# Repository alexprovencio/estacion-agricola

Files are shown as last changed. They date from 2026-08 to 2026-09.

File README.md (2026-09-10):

# Estación Agrícola Autónoma

Sistema de medición ambiental y del suelo para huertas al aire libre, construido como práctica final de **Sistemas Digitales para el Internet de las Cosas** y continuado en **Comunicaciones Inalámbricas y Protocolos para el Internet de las Cosas** (micromáster IoT, UNED, curso 2025/2026).

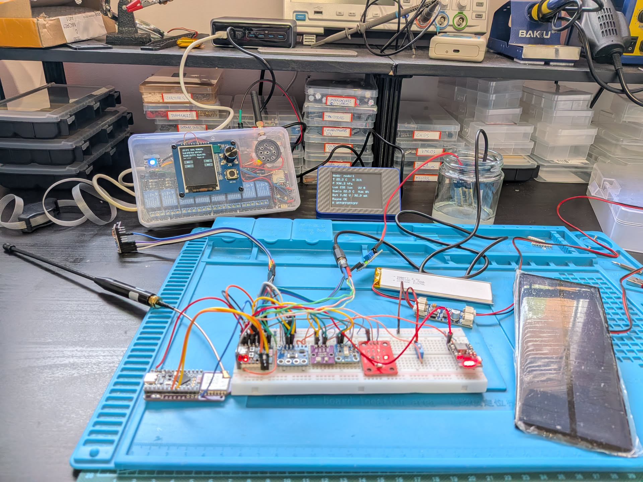
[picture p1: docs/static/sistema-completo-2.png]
Sistema completo


## Qué hace

Un **nodo autónomo** (ESP32-C3 SuperMini) mide *in situ* temperatura y humedad ambientales, presión atmosférica, iluminación, índice UV, humedad y temperatura del suelo y proximidad de tormentas. Envía sus lecturas en JSON cada 30 s a una **estación base** (Raspberry Pi 1 Model B) mediante LoRa con placas Faketec y firmware Meshtastic, aunque el enlace es intercambiable: WiFi con MQTT, ESP-NOW o USB directo. La estación base publica todo en un broker **Mosquitto** local, muestra los datos en pantalla, acciona relés, emite avisos de voz y los sube a la nube (Ubidots). Una **estación auxiliar** (Cheap Yellow Display o CYD) se conecta por WiFi al mismo broker para mostrar la telemetría y el estado de los relés en tiempo real.

## Estado del proyecto

- **Práctica Sistemas Digitales**: etiqueta [`sistemas-digitales-final`](https://github.com/alexprovencio/estacion-agricola/tree/sistemas-digitales-final).
- **Práctica Comunicaciones Inalámbricas**: rama `main`, memoria en [memoria-comunicaciones.md](docs/memoria-comunicaciones.md).

## Estructura del repositorio

```
├── nodo-autonomo/      Firmware del ESP32-C3 (pioarduino / Arduino), con varios targets de transporte
├── estacion-base/      Programa de la estación base (Python, paquete instalable) + broker Mosquitto
├── estacion-auxiliar/  Firmware del Cheap Yellow Display (ESP32 + TFT_eSPI)
├── puente-espnow/      Firmware del ESP32-C3 que hace de puente ESP-NOW
└── docs/               Memorias y material de referencia
```

## Documentación

Todo el detalle está en las memorias:

- [Memoria de Sistemas Digitales](docs/memoria-sistemas.md): arquitectura, sensores, conexiones, código, instalación y configuración del nodo y la estación base.
- [Memoria de Comunicaciones Inalámbricas](docs/memoria-comunicaciones.md): nodo solar, broker MQTT, enlaces WiFi/ESP-NOW/Meshtastic y comparación de prestaciones.
- [Diagrama de arquitectura](docs/arquitectura.mdd): flujo de datos entre nodo, gateway, broker, estación base y estación auxiliar.

## Nodo autónomo (firmware)

Proyecto [PlatformIO](https://platformio.org/) para el ESP32-C3 SuperMini con el framework Arduino y el fork `pioarduino` del core. Se compila y flashea con la extensión *pioarduino* de Visual Studio Code o desde terminal. El transporte se elige con el target de compilación:

```bash
cd nodo-autonomo
pio run -e esp32-c3-meshtastic --target upload   # LoRa/Meshtastic
pio run -e esp32-c3-wifi       --target upload   # WiFi + MQTT
pio run -e esp32-c3-espnow     --target upload   # ESP-NOW al puente
pio run -e esp32-c3-usb        --target upload   # USB-CDC directo a la base
```

El nodo se alimenta con panel solar y batería LiPo a través del cargador MPPT CN3791 y el convertidor MH-CD41, y mide su consumo con un INA226. Cada 30 s emite el payload JSON:

```json
{"nid":"nodo-1","seq":1,"t":31,"ta":25.9,"ha":30.1,"pa":935.1,"lx":771.8,"uv":23,"ts":24.1,"hs":2828,"vb":4,"ia":79.9,"pw":317.5,"re":"ok"}
```

La configuración (credenciales WiFi/MQTT, MAC del puente, canal ESP-NOW...) se copia de `include/secrets.h.example` a `include/secrets.h`. La lista de sensores, pines y librerías está en la [memoria](docs/memoria-comunicaciones.md#2-nodo-solar-autónomo).

## Estación base

Requisitos: Raspberry Pi con SPI y audio habilitados, las dependencias del sistema indicadas en la memoria, un broker **Mosquitto** local y Python 3.9 o superior.

```bash
cd estacion-base
python3 -m venv ~/venvs/estacion
source ~/venvs/estacion/bin/activate
pip install --upgrade pip
pip install -e .
cp .env.example .env          # tokens de Ubidots y credenciales del broker
sudo ~/venvs/estacion/bin/python -m estacion_base
```

Se ejecuta como `root` por el uso de DMA de la librería *neopixel* (ver memoria). El programa:

- Lee el nodo por el puerto serie (USB, puente ESP-NOW o Faketec Meshtastic) con el inyector `gateway_serial.py`, o directamente del broker si el nodo usa WiFi (`ENLACE_NODO=mqtt`), y publica en `esagrau/nodos/+/telemetria`.
- Se suscribe al broker local (TLS en el puerto `8883`) para procesar la telemetría y el estado de los relés.
- Dibuja en la pantalla, gestiona relés, encoder y avisos de voz, ejecuta automatismos locales y comunica con Ubidots cada 30 s.

## Estación auxiliar

Firmware para el Cheap Yellow Display (ESP32 con pantalla ILI9341 y TFT_eSPI). Se conecta por WiFi al broker de la estación base (puerto `1883`, sin TLS por limitaciones de la librería *AsyncMqttClient* en el ESP32) y se suscribe a `esagrau/nodos/+/telemetria` y `esagrau/base/estado` para mostrar las variables del nodo y el estado de los relés en tiempo real. Configuración en `include/secrets.h` (a partir de `secrets.h.example`).

```bash
cd estacion-auxiliar
pio run --target upload
```

## Puente ESP-NOW

Firmware para un segundo ESP32-C3 que recibe la telemetría del nodo por ESP-NOW y la reenvía por USB-CDC a la estación base, que la inyecta en el broker. Configuración en `include/secrets.h` (canal WiFi y MAC del nodo).

```bash
cd puente-espnow
pio run --target upload
```

## Broker MQTT

La estación base ejecuta un broker *Mosquitto* con un prefijo común `esagrau` (EStación AGRícola AUtónoma):

| Tema | Uso |
| :--- | :--- |
| `esagrau/nodos/{id}/telemetria` | Lecturas del nodo (QoS 1). |
| `esagrau/nodos/{id}/estado` | Presencia del nodo (retain, LWT en modo WiFi). |
| `esagrau/nodos/{id}/control` | Control puntual del nodo (uso futuro). |
| `esagrau/base/estado` | Estado de los relés de la estación base (retain). |
| `esagrau/base/control` | Petición de cambio de relés (base, auxiliar, Ubidots). |

La configuración del broker (`/etc/mosquitto/conf.d/local.conf`), los certificados y los usuarios se detallan en la [memoria](docs/memoria-comunicaciones.md#31-configuración-del-broker-mqtt).

## Conexiones

Los esquemas completos se generaron con Cirkit Designer y se citan en la [memoria de Sistemas Digitales](docs/memoria-sistemas.md), junto con la lista de pines del nodo (entradas analógicas, bus I2C, OneWire e interrupciones) y de la estación base (SPI para la pantalla, pines de relés, LED y botones). El nodo solar añade la etapa de alimentación (CN3791 + MH-CD41 + INA226) y las placas Faketec para LoRa.

## Configuración de Ubidots

La estación base publica en dos dispositivos separados: `nodo-1` con las lecturas de los sensores y `estacion-base` con el estado de los relés, que además pueden activarse a distancia desde el panel. Más detalle en la [memoria](docs/memoria-sistemas.md#4-plataforma-iot-en-la-nube-ubidots).

## Mejoras previstas

Las líneas de trabajo futuras están recogidas en las conclusiones de la [memoria de Comunicaciones Inalámbricas](docs/memoria-comunicaciones.md#6-conclusiones-y-mejoras-futuras) (pruebas en campo abierto, PCBs propios, carcasas 3D, escalabilidad a varios nodos, etc.) y de la [memoria de Sistemas Digitales](docs/memoria-sistemas.md#5-conclusiones-y-mejoras-futuras).

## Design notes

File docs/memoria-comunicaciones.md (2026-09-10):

# 1. Introducción

Esta práctica continúa la realizada en la asignatura de Sistemas Digitales para el Internet de las Cosas. Consiste en el desarrollo de un sistema completo de mediciones ambientales y del suelo para agricultura inteligente, para su uso en huertas, viveros, invernaderos o cultivos extensos, fundamentalmente de regadío.

El sistema realiza las siguientes mediciones mediante un nodo autónomo instalado *in situ*:

- Temperatura ambiente: para detectar estrés térmico por calor o frío excesivos y predecir heladas.
- Humedad relativa del aire: podemos anticipar la aparición de enfermedades debidas a la alta humedad y, combinado con la temperatura, calcular la transpiración de las plantas con el fin de dimensionar el riego.
- Presión atmosférica: ayuda a la previsión meteorológica local, por ejemplo, una rápida caída de la presión puede indicar lluvia, viento o una tormenta.
- Iluminación incluyendo IR: ayuda a detectar exceso o déficit de luz en las plantas, lo que puede alterar su crecimiento. En un invernadero o cultivo bajo cubierta serviría para ajustar la iluminación artificial.[^1]
- Índice UV: afecta a la calidad, sabor y conservación de los frutos, además, lo podemos usar para proteger a los operarios los días de mayor incidencia o regular el uso de lámparas UVA en cultivos de interior.[^2]
- Proximidad de tormentas: nos puede servir para recolectar los frutos antes de la llegada de la tormenta evitando su deterioro a causa del granizo o la lluvia excesiva, también a preparar nuestros cultivos ante la tormenta, y puede evitar gastos innecesarios derivados de la aplicación de fitosanitarios que se desperdiciarían si se aplican justo antes de la lluvia.
- Temperatura del suelo: nos ayuda a encontrar el momento óptimo para la siembra, puede servirnos para calcular la disponibilidad de nutrientes y detectar riesgos de heladas.[^3]
- Humedad del suelo: fundamentalmente nos indica cuando regar, evitando riego en exceso o defecto, ahorrando agua y detectando problemas de drenaje.

Todas estas mediciones las realiza un nodo autónomo (ESP32-C3 SuperMini), equipado con un panel solar y una batería de litio, que se instala en la zona a medir y cuyos datos se envían a una estación base (Raspberry Pi 1 Model B) para su procesamiento y envío a una plataforma IoT en la nube (*Ubidots*) para su análisis.

La estación base dispone a su vez de una pantalla para visualización de los datos y/o alertas del sistema, botones que controlan una serie de relés que podrían usarse para activar bombas de riego, luces... y un altavoz que emite alertas (por ejemplo ante la proximidad de una tormenta) y avisos.

También se ha creado una estación auxiliar que muestra los datos del nodo autónomo y el estado de los relés de la estación base en tiempo real.

Finalmente, la comunicación entre el nodo autónomo y la estación base se realiza mediante LoRa usando dispositivos auxiliares con *Meshtastic*[^4] conectados por UART. La estación base, que usa un broker MQTT local, está conectada por Ethernet a mi red local y la estación auxiliar se conecta por WiFi a este broker para obtener los datos del sistema y mostrarlos.

Foto del sistema completo con el nodo autónomo en primer plano y las estaciones base y auxiliar detrás. Se pueden ver las placas Faketec con Meshtastic del nodo y la estación.

# 2. Nodo solar autónomo

El nodo autónomo, gobernado por un ESP32-C3 Supermini de TENSTAR ROBOT[^5], cuenta con los siguientes sensores de ambiente/suelo:

- Sensor AHT20+BMP280: mide temperatura, humedad relativa y presión atmosférica ambientales. El módulo que tengo combina ambos sensores y funciona por I2C.
- Sensor VEML7700: mide la luz ambiental real de forma lineal y con alta precisión y funciona por I2C. Rango de medición de 0 a 120.000 lux, detecta luz visible e IR.
- Sensor GUVA-S12SD: calcula el índice UV para luces de longitudes de onda de 240 nm a 370 nm con salida analógica y salida entre 0 y 1 V.
- Sensor AS3935: usado para detectar rayos y estimar la distancia a la tormenta. Puede detectar rayos hasta a 40 km con una precisión de 1 km en 14 pasos. Tiene un pin de alerta que conecto al ESP32-C3 para avisar de descargas en tiempo real mediante el uso de una interrupción y la lectura de un registro. Se puede conectar usando SPI o I2C, lo conecto usando I2C.
- Higrómetro de suelo FC-28: mide la humedad de la tierra usando un sensor simple por variación de conductividad. Uso la salida analógica con el ADC de 12 bits del ESP32-C3 para obtener valores entre 0 y 4096.
- Sonda Sumergible DS18B20: mide la temperatura, la emplearemos enterrada en la tierra. Usa el protocolo *OneWire*.

Los siguientes componentes se encargan de la alimentación:

- Sensor INA226: mide voltaje y corriente de la batería de litio conectada al sistema para calcular su carga y lo que consumimos. Funciona mediante I2C. Al hacer pruebas vi que el INA226 no me devolvía datos de corriente porque no había inicializado bien la librería con el registro de calibración: el valor del *shunt*, que en mi módulo es 0,1 Ω, y la corriente máxima medible, que según he visto es de alrededor de 0,8 A.
- Convertidor/Cargador MH-CD41: este módulo permite cargar baterías y además integra un convertidor a 5V, botón de encendido/apagado e indicador de carga. No lo empleo para cargar la batería, de eso se encarga el siguiente módulo.
- Cargador solar MPPT CN3791: eficiente módulo controlador de punto de máxima potencia para cargar baterías LiPo 1S desde un panel solar.
- Batería: LiPo de 1 Ah a 3,7 V para las pruebas.
- Panel solar: 165x65 mm de tamaño a 6 V con una salida máxima de 250 mA (1,5 W) para las pruebas.

Y para las comunicaciones con la estación base:

- Faketec V4[^6]: PCB con una placa de desarrollo con un nRF52840[^7] y una radio HT-RA62[^8] LoRa y firmware *Meshtastic*. Conectada por UART y que hace de pasarela con otra placa idéntica conectada a la estación base.

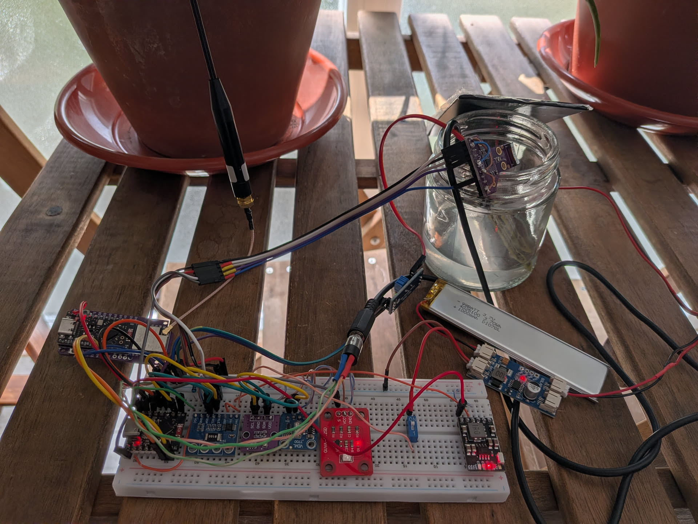
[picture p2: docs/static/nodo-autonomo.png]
Nodo autónomo en funcionamiento.


# 3. Estación base

La estación base, controlada por una Raspberry Pi 1 Model B, tiene los siguientes periféricos conectados mediante GPIO:

- Pantalla: la empleo para mostrar los datos recibidos del nodo, incluyendo alertas, y controlar los relés conectados a la estación base. Uso un módulo con una pantalla de 2 pulgadas con un codificador rotatorio y un botón extra integrados. Se conecta por SPI.
- LED de estado: empleado para indicar el estado del sistema. Uso un WS2812B conectado directamente.
- Amplificador y altavoz: usados para emitir alertas y avisos. Empleo un módulo con un PAM8302A, conectado al jack de 3,5 mm y a un pequeño altavoz de 8 Ω y 0,5 W.
- Relés: uso también un módulo con 8 relés para simular la apertura de válvulas de riego y la activación de otros sistemas. Solo conecto 4 de los relés, más que suficientes para realizar pruebas, y uso sus LEDs de estado para comprobar que funcionan correctamente.
- Faketec V4: idéntico al del nodo autónomo, conectado por UART usando los GPIO de la Raspberry Pi. Hay que activar el puerto y deshabilitar la consola en la configuración de *DietPi*.

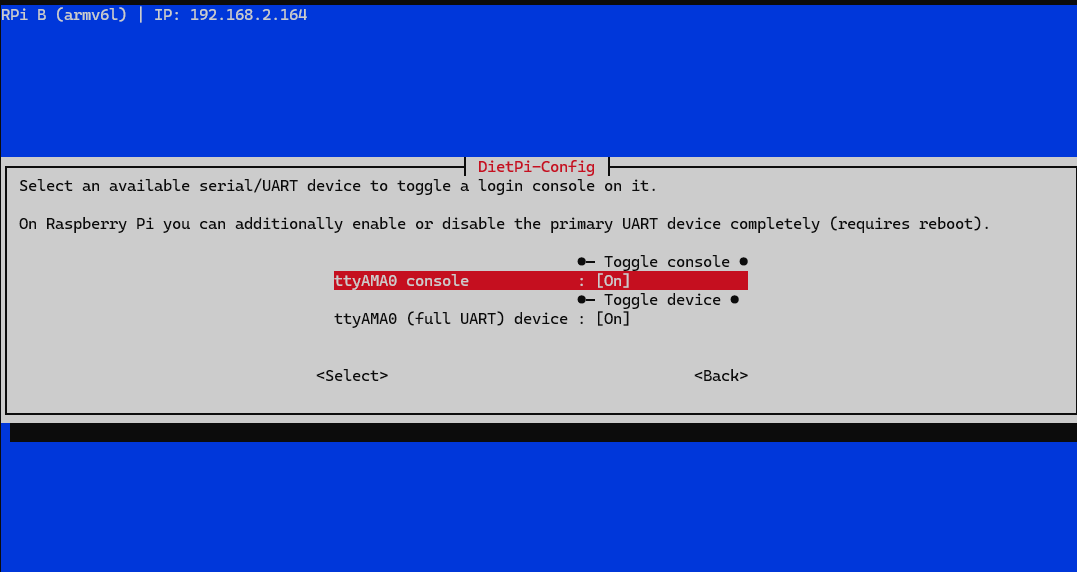
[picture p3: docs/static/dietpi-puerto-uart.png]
Configuración del puerto UART en DietPi


## 3.1. Configuración del broker MQTT

Instalo un broker *Mosquitto*[^9] en la Raspberry Pi. Lo hago usando el gestor de software de *DietPi*. El proceso de instalación se detalló en la Práctica 1 de la asignatura. Añado mi propia configuración en `/etc/mosquitto/conf.d/local.conf` para hacerlo más seguro, aunque como se ve he dejado la conexión insegura usando el puerto `1883` por simplicidad, lo ideal sería eliminarla y que todos los clientes se conectaran usando el puerto `8883`.

```bash
listener 1883 0.0.0.0
allow_anonymous false
password_file /etc/mosquitto/passwd

listener 8883 0.0.0.0
allow_anonymous false
cafile /etc/mosquitto/certs/ca.crt
certfile /etc/mosquitto/certs/server.crt
keyfile /etc/mosquitto/certs/server.key
require_certificate false
tls_version tlsv1.2
```

Creo usuarios y contraseñas para `nodo-1`, `estacion-base` y `estacion-aux` usando `mosquitto_passwd`. Genero los certificados autofirmados pertinentes para la conexión segura y finalmente reinicio el broker usando `sudo dietpi-services restart mosquitto`. El único cliente que usa la conexión segura con el broker MQTT es la propia estación base en local, debido a las limitaciones de tiempo que tenía y a los problemas que me dio la librería para manejo de MQTT que usé en los ESP32.

A continuación paso a diseñar los temas que usaré para todos los dispositivos que se conectan a este broker. Uso *ESAGRAU* como prefijo diferenciador, que son las siglas de EStación AGRícola AUtónoma:

| Tema | Dirección | QoS | Retain | Payload (ejemplo) | Descripción |
| :--- | :---: | :---: | :---: | :--- | :--- |
| `esagrau/nodos/{id}/telemetria` | Nodo → Base | 1 | No | `{"nid":"nodo-1","seq":1,"t":31,"ta":25.9...}` | Medida periódica cada 30 s. Las estaciones base y auxiliar son las suscriptoras (`esagrau/nodos/+/telemetria`). |
| `esagrau/nodos/{id}/estado` | Nodo → Base | 1 | Sí | `{"estado":"online","rssi":-42,"snr":3.5,"bateria":4.08}` o con LWT `{"estado":"offline"}` | Presencia. Con `retain` la estación sabe si el nodo está vivo al reconectar. Se usa como *Last Will* de MQTT solo para el modo WiFi. |
| `esagrau/nodos/{id}/control` | Base → Nodo | 1 | No | `{"accion":"reboot"}` / `{"accion":"set","param":"interval","valor":10}` | Control puntual de los nodos. Para uso futuro. |
| `esagrau/base/estado` | Base → Auxiliar, *Ubidots* y Base | 0 | Sí | `{"rele_1":1,"rele_2":0,...}` | Estado de la estación base para la estación auxiliar, *Ubidots* y la propia estación base |
| `esagrau/base/control` | Auxiliar, *Ubidots* y Base → Base | 1 | No | `{"rele_1":0/1}` deseado | Solo la base, que es la que activa los relés, se suscribe. |
| `esagrau/nodos/+/telemetria` | — | — | — | — | Comodín al que se suscribirán las estaciones base y auxiliares cuando haya varios nodos. |

De esta forma evitamos rebotes ya que el único cliente que lee de `esagrau/base/control` para activar los relés es la propia estación base, y la única que actualiza el estado real de los relés en `esagrau/base/estado` también es la propia estación base.

## 3.2. Programa de monitorización y control

La parte de la pantalla, botones y sonido no ha sufrido cambios relevantes, solo adaptaciones. Se ha creado una parte nueva encargada de la medición de la calidad de conexión cuando se usa enlace por WiFi y una puerta de enlace que lee la telemetría que llega por puerto serie (enlace por USB, ESP-NOW o *Meshtastic*) y la publica en el broker local. Así hacemos el resto del programa transparente al método de enlace entre la estación base y el nodo autónomo.

Uso la versión 2.x de la librería *paho-mqtt*[^10] para comunicarme con mi broker local *Mosquitto* de forma segura, al menos desde la propia estación base. Se controlan las posibles excepciones y se mejora la detección de presencia del nodo autónomo y su reconexión.

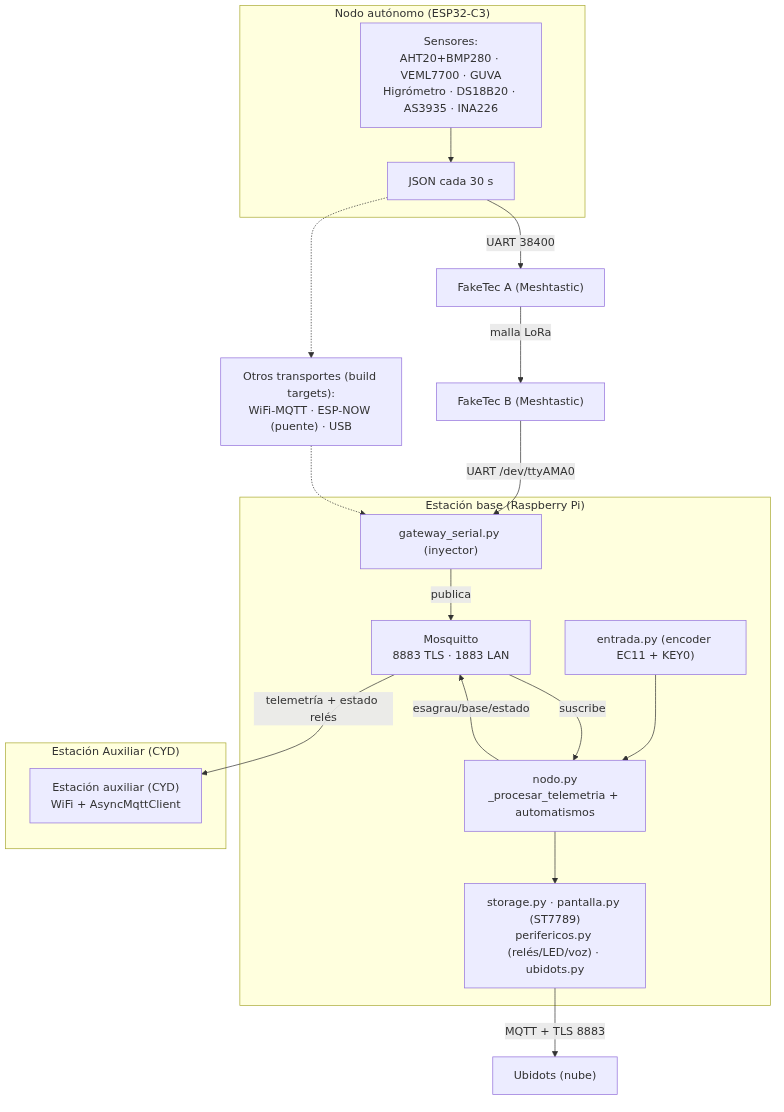
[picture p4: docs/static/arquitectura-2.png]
Arquitectura del programa y flujo de datos


## 3.3. Comunicación con Ubidots

Pasamos a usar MQTT para conectarnos; ahora tanto las alertas de rayos como el estado y control de los relés se actualizan al momento.

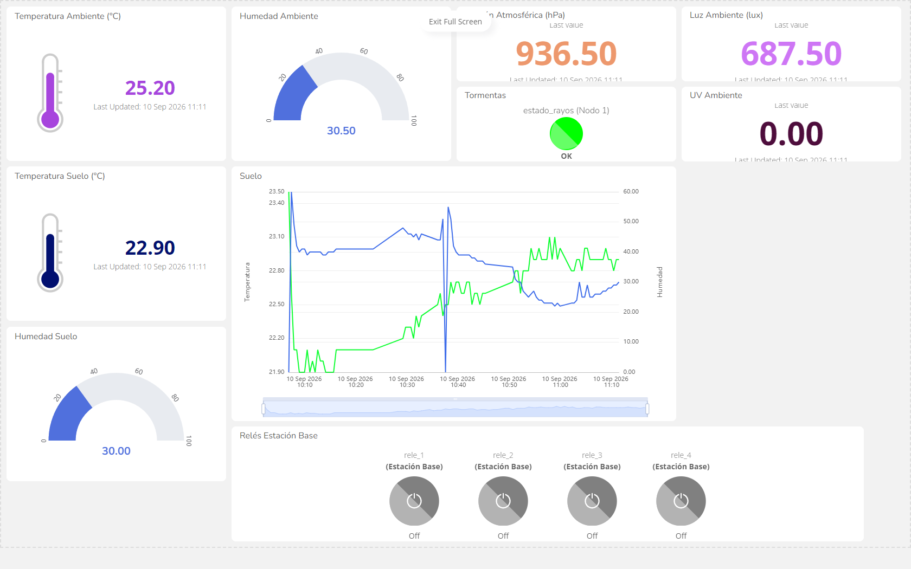
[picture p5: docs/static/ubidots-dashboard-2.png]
Panel de control Ubidots


# 4. Estación auxiliar

Uso un Cheap Yellow Display[^11] para mostrar los mismos datos que la pantalla de la estación base. El CYD se conecta por WiFi a la misma red local donde está conectada la estación base y accede a su broker *Mosquitto* para recibir datos.

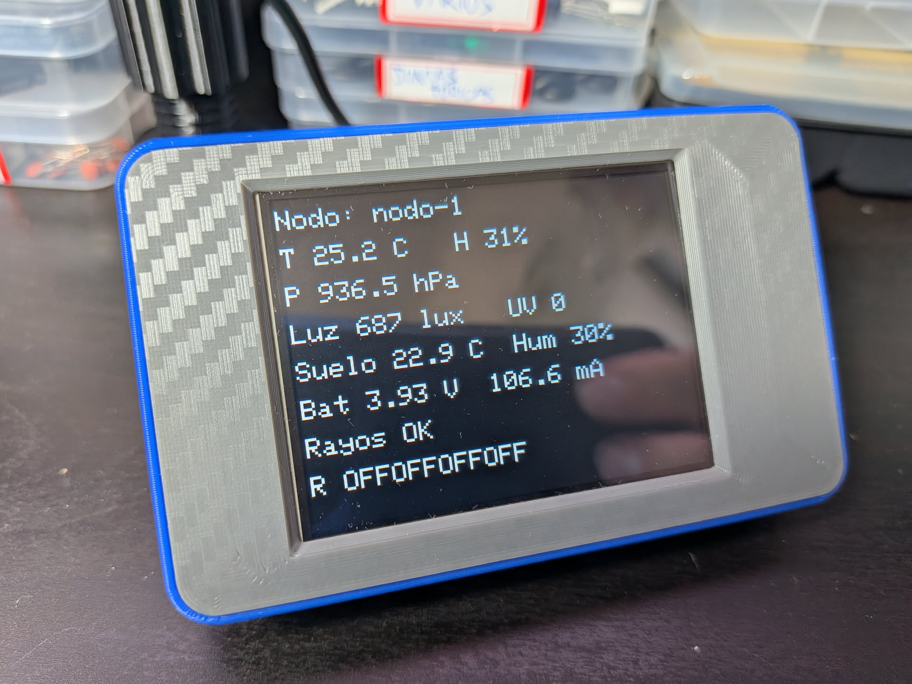
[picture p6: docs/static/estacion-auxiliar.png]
Estación auxiliar mostrando datos del nodo autónomo y estado de los relés de la base.


El programa es sencillo y la conexión con el servidor MQTT se hace usando usuario y contraseña, pero en claro, por el puerto `1883`, por limitaciones de tiempo y porque la librería que empleo[^12] para conectarme en teoría debería soportar la conexión segura usando SSL/TLS pero en la práctica no funciona, al menos con mi ESP32.

# 5. Comunicación del nodo autónomo con la estación base

El sistema desarrollado para la anterior práctica usaba el puerto USB para comunicarse con la estación base. Para esta ocasión hemos realizado pruebas con WiFi, usando un broker MQTT instalado en la propia estación base, ESP-NOW y finalmente LoRa con *Meshtastic*.

Tras varias iteraciones para reducir su tamaño debido a problemas de transmisión (especialmente con *Meshtastic*) finalmente uso este formato de payload que transmito a la estación base:

```json
{"nid":"nodo-1","seq":1,"t":31,"ta":25.9,"ha":30.1,"pa":935.1,"lx":771.8,"uv":23,"ts":24.1,"hs":2828,"vb":4,"ia":79.9,"pw":317.5,"re":"ok"}
```

| Campo | Tipo | Descripción |
|---|---|---|
| `nid` | string | id del nodo autónomo |
| `seq` | int | número del paquete para detectar pérdidas en las pruebas |
| `t` | int | tiempo de actividad del nodo en segundos (`millis()/1000`) |
| `ta` | float °C | temperatura ambiente (AHT20) |
| `ha` | float % | humedad relativa ambiente (AHT20) |
| `pa` | float hPa | presión atmosférica (BMP280) |
| `lx` | float lux | iluminación (VEML7700) |
| `uv` | int 0-4095 | ADC raw del GUVA-S12SD |
| `ts` | float °C | temperatura del suelo (DS18B20) |
| `hs` | int 0-4095 | ADC raw del higrómetro |
| `vb` | float V | tensión de la batería (INA226) |
| `ia` | float mA | corriente de la batería (INA226) |
| `pw` | float mW | carga del sistema (INA226) |
| `re` | int | `0-ok` \| `1-ruido` \| `2-disturber` \| `3-rayo` (AS3935) |
| `rd` | int km | distancia al frente de tormenta (solo si `re`=3) |

Paso a continuación a comentar los detalles de implementación de los diferentes métodos de comunicación probados.

## 5.1. UART por USB

Inicialmente usé la conexión por USB que ya tenía en la práctica de Sistemas Digitales para el Internet de las Cosas y comprobé que funcionaba bien el cambio a MQTT tanto en la estación base como en *Ubidots*.

## 5.2. WiFi

Empleo directamente el broker MQTT de la estación base con la librería *AsyncMqttClient*. Uso el ejemplo disponible para el ESP32[^13] para realizar mi implementación. Iba a usar los *timers* de *FreeRTOS* invocados expresamente para realizar reconexiones sin bloquear el *loop* principal y no tener que crear hilos tal como se hace en el ejemplo, pero me enteré de que el núcleo de ESP32 para *Arduino* ya corre de forma nativa sobre *FreeRTOS*[^14]. Yo he usado *FreeRTOS* antes en microcontroladores STM32, por lo que la integración nativa en los ESP32 es una buena noticia, le sacaré partido de aquí en adelante.

Para las pruebas con el WiFi uso la librería integrada en el núcleo del ESP32[^15] y creo un AP en el nodo autónomo al que se conectará la estación base. Hay que prestar atención a no configurar un gateway para esta conexión o perderemos la conexión a internet por Ethernet.

Para empezar, la Raspberry Pi daba problemas de alimentación con el WiFi USB, lo tengo que conectar con ella apagada y aun así hay veces que no lo reconoce o que no conecta si el nodo no estaba encendido antes. No me avisa por pantalla cuando el nodo se desconecta, lo cambié usando un dibujo similar al de rayo y un aviso sonoro. Uso el LWT del broker MQTT para detectar el estado desconectado del nodo autónomo.

Pongo un hub USB alimentando tanto a la Raspberry Pi como al USB WiFi y a todo lo que conecte por USB y así el sistema es más estable.

## 5.3. ESP-NOW

Para la comunicación por ESP-NOW[^16], nativa de los ESP32, empleo otro ESP32-C3 idéntico al que gobierna el nodo autónomo conectado por USB a la estación base. El nodo autónomo mandará la telemetría que la estación base leerá a través de esta puerta de enlace por el puerto serie de manera análoga a como lo hacíamos con la conexión directa por USB.

Al implementar la comunicación usando este protocolo me di cuenta de que *PlatformIO* no actualizaba ya el core *Arduino* del ESP32 debido a problemas entre las empresas[^17]. Pasé aquí a usar el fork *pioarduino*[^18] que incluye el último core con soporte para ESP-NOW v2.0 y que me permite un mayor tamaño del payload.

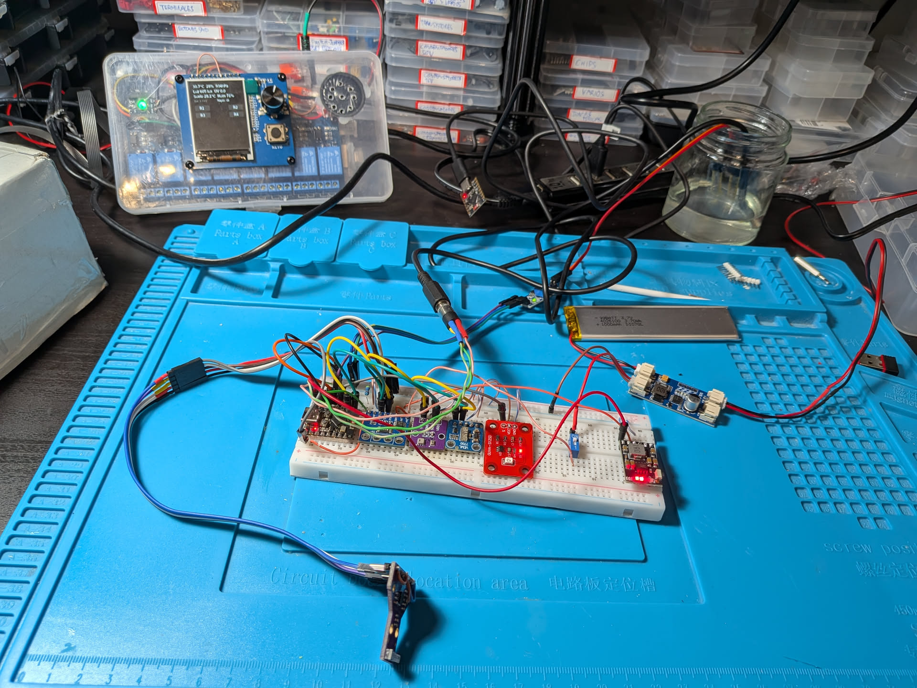
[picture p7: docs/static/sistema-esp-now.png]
El sistema usando ESP-NOW como método de enlace.


Al no ser ESP-NOW un protocolo IP, sino un enlace punto a punto *connectionless*, necesitamos un gateway que traduzca a IP para mandar la telemetría recibida al broker. Usamos para ello la propia estación base y así el código nos vale para republicar lo que recibimos del Faketec con enlace usando *Meshtastic* y retroactivamente lo usamos para conexión directa usando USB. Como ventaja, la comunicación se siente muy rápida, sin los problemas de conexión que daba WiFi y con reconexión inmediata.

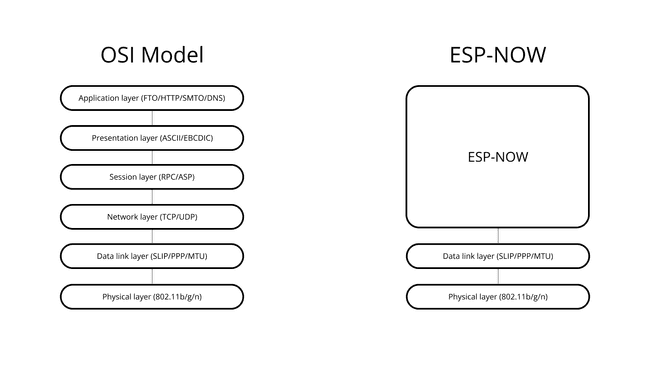
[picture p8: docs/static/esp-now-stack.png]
Pilas de TCP/IP y ESP-NOW. Fuente: Arduino Docs


## 5.4. Meshtastic

Para la comunicación por LoRa usando *Meshtastic* empleo dos Faketec V4 con nRF52840 y firmware *Meshtastic* que tenía hechos anteriormente y que servirán de pasarelas entre el nodo autónomo y la estación base.

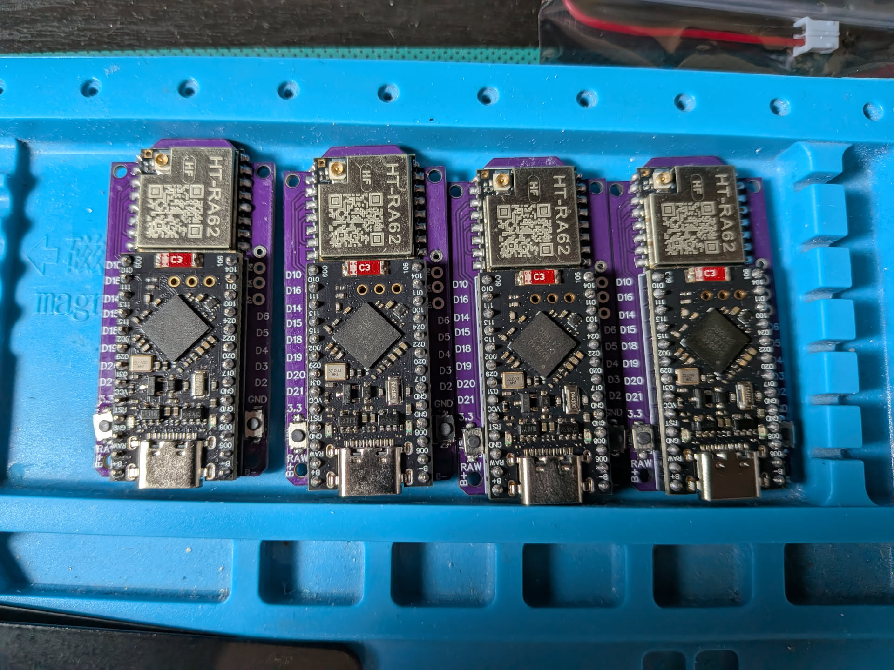
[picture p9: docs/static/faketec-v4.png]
Varios Faketec que hice para pruebas con *Meshtastic*


Uso la app de *Meshtastic* desde el móvil para configurar los Faketec con un canal principal que compartirán y su respectiva clave, activo también el puerto serie[^19] y configuro los pines que se usarán para comunicarse con la Raspberry Pi y el ESP32-C3 y el modo *TEXTMSG*, que reenvía por el canal principal todo lo que recibe por el puerto serie y viceversa.

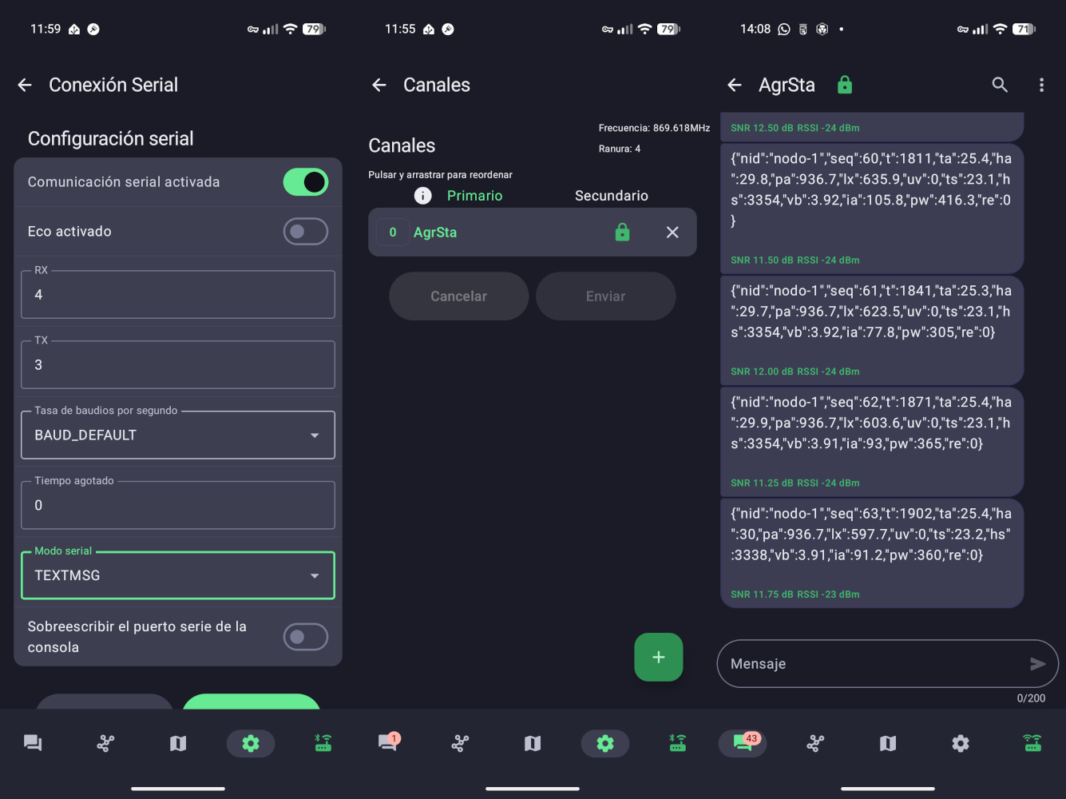
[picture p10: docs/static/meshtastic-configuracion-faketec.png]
Varios Faketec que hice para pruebas con *Meshtastic*


Inicialmente me fallaba la transmisión cuando usaba batería en el nodo autónomo porque el payload era grande y sobrepasaba el límite de 240 bytes de *Meshtastic*, lo compacté redondeando *floats* a 1 decimal (excepto para la tensión de la batería).

Ahora mismo mandamos los datos del nodo autónomo cada 30 segundos, aunque en realidad debería ser con más tiempo entre envíos. Surgió un problema debido a que este es el tiempo que tardamos en leer el registro de interrupción del sensor de rayos; si después de un rayo hay interferencias o ruido, perdemos el evento de rayo detectado anteriormente. Lo corrijo guardando en un registro temporal el dato más crítico del registro de interrupción para enviarlo con el siguiente paquete. Lo hago como tarea porque hacerlo directamente en el ISR no es correcto al tener que leer el I2C.

## 5.5. Comparación entre métodos de comunicación

Implementé el campo `seq` con números secuenciales en el payload para saber si perdemos paquetes y creé un par de scripts para analizar los logs que guardamos y extraer de ellos valores que nos sirvan para comparar los diferentes métodos de comunicación entre el nodo autónomo y la estación base.

Todas las pruebas se ejecutan durante 10 minutos; la frecuencia de envío de telemetría es de 5 segundos para todos los métodos, menos para *Meshtastic*, donde es de 30 segundos.

Para el WiFi ejecuté a la vez pings para comprobar latencias y pérdida de paquetes y un *scan* para ver cuántas redes había y qué canales usaban. El nivel RSSI para *Meshtastic* es aproximado sacado de los datos de los paquetes.

| prueba | dist | n_rx | PDR% | perd | dt med/p95 s | RSSI med/min (n) | ping loss% | RTT min/avg/max/mdev ms | Vbat | I mA | APs | canales |
|---|---|---|---|---|---|---|---|---|---|---|---|---|
| T0_0m_WiFi | 0.3 | 115 | 100.0 | 0 | 5.17/5.19 | -39.0/-42 (n=115) | 0.0 | 1.665/3.222/61.454/3.531 | 3.81 | 182.25 | 25 | [1, 2, 4, 6, 10, 11] |
| T1_10m_LOS_WiFi | 10 | 116 | 100.0 | 0 | 5.17/5.21 | -69.8/-78 (n=116) | 0.0 | 4.067/15.569/93.774/10.148 | 3.8 | 183.94 | 11 | [1, 2, 4, 6, 10, 11] |
| T2_10m_VLOS_WiFi | 10 | 115 | 100.0 | 0 | 5.17/5.2 | -73.3/-76 (n=115) | 0.333333 | 2.577/7.344/212.359/11.513 | 3.75 | 186.2 | 11 | [1, 2, 4, 6, 10, 11] |
| T5_usb | 0.3 | 116 | 100.0 | 0 | 5.17/5.18 | None/None (n=0) | - | -/-/-/- | - | - | - | - |
| T6_0m_ESP-NOW | 0.3 | 116 | 100.0 | 0 | 5.17/5.43 | -48.1/-50 (n=116) | - | -/-/-/- | 3.71 | 182.09 | - | - |
| T7_10m_LOS_ESP-NOW | 10 | 115 | 100.0 | 0 | 5.17/5.46 | -79.6/-88 (n=115) | - | -/-/-/- | 3.72 | 178.68 | - | - |
| T8_10m_VLOS_ESP-NOW | 10 | 116 | 100.0 | 0 | 5.17/5.42 | -78.0/-82 (n=116) | - | -/-/-/- | 3.7 | 180.66 | - | - |
| T11_0m_Meshtastic | 0.3 | 20 | 100.0 | 0 | 30.17/30.48 | -36/-41 (n=20) | - | -/-/-/- | 3.87 | 83.03 | - | - |
| T12_10m_Meshtastic | 10 | 20 | 100.0 | 0 | 30.18/30.36 | -23/-24 (n=20) | - | -/-/-/- | 3.95 | 89.97 | - | - |
| T13_10m_VLOS_Meshtastic | 10 | 20 | 100.0 | 0 | 30.18/30.54 | -23/-24 (n=20) | - | -/-/-/- | 3.93 | 92.91 | - | - |

Notas:
- T0_0m_WiFi: lado a lado
- T1_10m_LOS_WiFi: LOS
- T2_10m_VLOS_WiFi: VLOS
- T5_usb: USB directo
- T6_0m_ESP-NOW: ESP-NOW lado a lado
- T7_10m_LOS_ESP-NOW: ESP-NOW línea con visión directa
- T8_10m_VLOS_ESP-NOW: ESP-NOW línea con una puerta cerrada en medio
- T11_0m_Meshtastic: Meshtastic lado a lado
- T12_10m_Meshtastic: Meshtastic línea con visión directa
- T13_10m_VLOS_Meshtastic: Meshtastic línea con una puerta cerrada en medio

Como se puede comprobar, por limitaciones de tiempo no pude llevar a cabo las muy necesarias pruebas en campo abierto. De los resultados en interior podemos deducir que LoRa sería el mejor método de comunicación para distancias largas (yo he probado enlaces a 20 km sin problema), pese a su mayor *jitter*, además de que el nodo autónomo consume significativamente menos que con los métodos que emplean WiFi.

# 6. Conclusiones y mejoras futuras

He empleado bastante más tiempo del que había planificado para realizar esta práctica, principalmente por los objetivos que me había marcado al principio, esto es, la prueba de varios sistemas de comunicación en vez de usar directamente *Meshtastic*, que era mi objetivo final.

Entre las mayores pérdidas de tiempo sin sentido están los problemas que me dio la conexión entre el ESP32-C3 y el Faketec porque estaba convencido de que la numeración de los pines en *Meshtastic* se correspondía con la impresa en la PCB donde van soldados los módulos, cuando en realidad su numeración es la del nRF52. Incluso tuve que emplear el osciloscopio porque no me creía que el ESP32 estuviera enviando nada por sus puertos.

Hay muchas mejoras que se pueden implementar en el sistema, entre ellas destaco:

- Mejorar la UI de la estación base, incluir RSSI y SNR del enlace *Meshtastic*.
- Usar el "sender:" que *Meshtastic* antepone a los mensajes que recibimos para identificar al nodo que los envía y quitar su id del payload.
- Cambiar el protocolo serie de los Faketec para usar *PROTO* en vez de *TEXTMSG* y exponer así su API completa.
- Probar el sistema con varios nodos autónomos para ver si es escalable.
- Modificar el programa de la estación base para que sea instalable como un servicio y se inicie automáticamente cada vez que la arranquemos y además podamos monitorizar su estado. Igualmente, cambiar la ubicación del log para usar los del sistema.
- Realizar cajas impresas en 3D diseñadas a medida tanto para el nodo autónomo, separando los sensores que necesitan estar en el exterior con sus propias carcasas, como para la estación base.
- Usar *mosfets*, como el Si2312, para apagar los sensores cuando no se utilizan en el nodo autónomo y así ahorrar energía.
- Añadir al nodo autónomo un sensor de pluviometría para registrar el nivel de lluvia y un anemómetro y veleta para registrar la velocidad y dirección del viento.
- Usar un ESP32-C6 reemplazando al ESP32-C3 empleado por ser la última versión de esta gama y tener mejor conectividad, aunque en principio nosotros no emplearemos ni WiFi ni Bluetooth para comunicarnos, sí que se podría hacer algo usando la conexión Matter (IEEE 802.15.4) integrada.
- Usar el microcontrolador del nodo autónomo para controlar el módulo de radio LoRa directamente sin necesidad de usar los Faketec.
- Firmware del nodo autónomo actualizable vía *OTA*, uso de *secure boot*.
- Usar mejores sensores de suelo ya que los empleados se corroen fácilmente como he comprobado.
- Crear PCBs para todo el sistema, especialmente para el nodo autónomo, y así reducir su tamaño y coste.
- Mejorar la estación auxiliar para incluir el accionamiento de los relés, la UI e integrar algún sensor que podamos mandar al broker MQTT de la estación base.
- Estudiar las implicaciones de usar una red pública para nuestros nodos, está muy bien para que el resto nos haga de relay, pero no es para nada recomendable sobrecargar la red con nuestras comunicaciones privadas. Al menos aumentar significativamente el tiempo entre lecturas.
- Modificar el firmware del nodo autónomo para que sus valores modificables de `secrets.h` sean configurables con software después de flashearlo con un firmware genérico poniéndolos como `params`.
- Posibilidad de mandar comandos desde la estación base, reinicios aunque sea, al nodo autónomo.
- Posibilidad de difundir los mensajes en un canal normal bajo petición expresa, en el canal Bots, por ejemplo.
- Posibilidad de transmitir también a la red *Meshtastic* los datos ambientales y del INA226 que soporte el protocolo nativamente para que se muestren a todos los usuarios de la malla.

[^1]: UPRtek - El Espectro UVA en la Agricultura de Interior: Mejora de la calidad y el rendimiento de los cultivos con iluminación UV-A. Disponible en: <https://www.uprtek.com/es/blogs/indoor-agriculture-leveraging-the-power-of-uva-spectrum>. Accedido el 2/9/2026.
[^2]: Hydro Environment - Guía Práctica: La Importancia de la Luz en el Cultivo. Disponible en: <https://hydroenv.com.mx/guia-practica-la-importancia-de-la-luz-en-el-cultivo/>. Accedido el 2/9/2026.
[^3]: EOS Data Analytics - Temperatura Del Suelo Para La Siembra Y El Cultivo. Disponible en: <https://eos.com/es/blog/temperatura-del-suelo/>. Accedido el 2/9/2026.
[^4]: Comunidad Meshtastic España. Disponible en: <https://meshtastic.es/>. Accedido el 10/9/2026.
[^5]: TENSTAR ROBOT - Placa de desarrollo TENSTAR ROBOT ESP32 C3 SuperMini. Disponible en: <https://tenstar.pro/robot-esp32-c3-supermini/>. Accedido el 24/8/2026.
[^6]: GitHub - fakeTec_pcb. Disponible en: <https://github.com/gargomoma/fakeTec_pcb>. Accedido el 10/9/2026.
[^7]: nordicsemi.com - nRF52840 - Bluetooth SoC. Disponible en: <https://www.nordicsemi.com/Products/nRF52840>. Accedido el 10/9/2026.
[^8]: Heltec Automation - HT-RA62. Disponible en: <https://heltec.org/project/ht-ra62/>. Accedido el 10/9/2026.
[^9]: Eclipse Mosquitto - An open source MQTT broker. Disponible en: <https://mosquitto.org/>. Accedido el 10/9/2026.
[^10]: PyPi - paho-mqtt 2.1.0. Disponible en: <https://pypi.org/project/paho-mqtt/>. Accedido el 10/9/2026.
[^11]: GitHub - ESP32-Cheap-Yellow-Display. Disponible en: <https://github.com/witnessmenow/ESP32-Cheap-Yellow-Display>. Accedido el 10/9/2026.
[^12]: GitHub - async-mqtt-client. Disponible en: <https://github.com/marvinroger/async-mqtt-client>. Accedido el 10/9/2026.
[^13]: PlatformIO Registry - Examples · marvinroger/AsyncMqttClient. Disponible en: <https://registry.platformio.org/libraries/marvinroger/AsyncMqttClient/examples/FullyFeatured-ESP32/FullyFeatured-ESP32.ino>. Accedido el 10/9/2026.
[^14]: ESP-IDF Programming Guide latest documentation - FreeRTOS Overview - ESP32. Disponible en: <https://docs.espressif.com/projects/esp-idf/en/latest/esp32/api-reference/system/freertos.html>. Accedido el 10/9/2026.
[^15]: Arduino-ESP32 2.0.14 documentation - Wi-Fi API. Disponible en: <https://espressif-docs.readthedocs-hosted.com/projects/arduino-esp32/en/latest/api/wifi.html>. Accedido el 10/9/2026.
[^16]: ESP-IDF Programming Guide v6.1 documentation - ESP-NOW - ESP32-C3. Disponible en: <https://docs.espressif.com/projects/esp-idf/en/stable/esp32c3/api-reference/network/esp_now.html>. Accedido el 10/9/2026.
[^17]: GitHub platformio - Support Arduino ESP32 v3.0 based on ESP-IDF v5.1. Disponible en: <https://github.com/platformio/platform-espressif32/issues/1225#issuecomment-4216264938>. Accedido el 10/9/2026.
[^18]: GitHub - pioarduino. Disponible en: <https://github.com/pioarduino>. Accedido el 10/9/2026.
[^19]: Meshtastic - Serial Module Configuration. Disponible en: <https://meshtastic.org/docs/configuration/module/serial/>. Accedido el 10/9/2026.

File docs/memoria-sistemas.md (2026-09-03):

# 1. Introducción

La idea para este trabajo es realizar un sistema completo de mediciones ambientales y del suelo para agricultura inteligente. En principio lo he diseñado para usarlo en huertas, viveros, invernaderos o cultivos extensos, fundamentalmente de regadío. Como ejemplo de empresa de mi zona que podría emplearlo están los viveros El Ejidillo[^2] en Valdesimonte, Segovia, con un terrero de cultivo de 65 hectáreas.

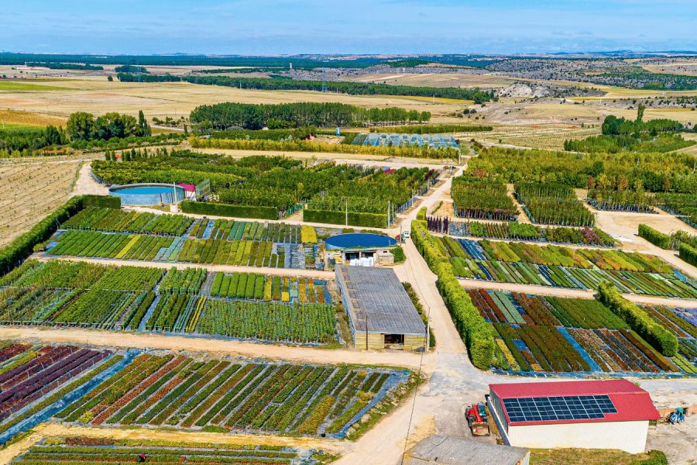
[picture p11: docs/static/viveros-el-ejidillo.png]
Fotografía de los viveros El Ejidillo


El sistema realizará las siguientes mediciones mediante un nodo autónomo instalado *in situ*:

- Temperatura ambiente: para detectar estrés térmico por calor o frío excesivos y predecir heladas.
- Humedad relativa del aire: podemos anticipar la aparición de enfermedades debidas a la alta humedad y, combinado con la temperatura, calcular la transpiración de las plantas con el fin de dimensionar el riego.
- Presión atmosférica: ayuda a la previsión meteorológica local, por ejemplo, una rápida caída de la presión puede indicar lluvia, viento o una tormenta.
- Iluminación incluyendo IR: ayuda a detectar exceso o déficit de luz en las plantas, lo que puede alterar su crecimiento. En un invernadero o cultivo bajo cubierta serviría para ajustar la iluminación artificial.[^17]
- Índice UV: afecta a la calidad, sabor y conservación de los frutos, además, lo podemos usar para proteger a los operarios los días de mayor incidencia o regular el uso de lámparas UVA en cultivos de interior.[^16]
- Proximidad de tormentas: nos puede servir para recolectar los frutos antes de la llegada de la tormenta evitando su deterioro a causa del granizo o la lluvia excesiva, también a preparar nuestros cultivos ante la tormenta, y puede evitar gastos innecesarios derivados de la aplicación de fitosanitarios que se desperdiciarían si se aplican justo antes de la lluvia.
- Temperatura del suelo: nos ayuda a encontrar el momento óptimo para la siembra, puede servirnos para calcular la disponibilidad de nutrientes y detectar riesgos de heladas.[^18]
- Humedad del suelo: fundamentalmente nos indica cuando regar, evitando riego en exceso o defecto, ahorrando agua y detectando problemas de drenaje.

Todas estas mediciones serán efectuadas por un nodo autónomo (ESP32-C3 SuperMini) que se instalaría en la propia huerta y cuyos datos se enviarán a una estación base (Raspberry Pi 1 Model B) para su procesamiento y envío a una plataforma IoT en la nube (*Ubidots*) para su análisis.

La estación base dispondrá a su vez de una pantalla para visualización de los datos y/o alertas del sistema, botones que controlarán una serie de relés que, hipotéticamente, podrían activar bombas de riego, luces... y un altavoz que emitirá alertas (por ejemplo ante la proximidad de una tormenta) y avisos.

El sistema se diseñará, en esta primera etapa, con una conexión simple por el puerto USB entre el nodo autónomo y la estación base, con la idea de mejorar el sistema de comunicaciones entre ambos en la práctica final de la asignatura Comunicaciones Inalámbricas y Protocolos para el Internet de las Cosas. El diseño se ha hecho pensando que sea fácilmente escalable para que una sola estación base pueda gestionar múltiples nodos autónomos, aunque no lo he probado ni optimizado para ese caso.

Cabe señalar que he decidido aprovechar buena parte del hardware que ya tenía para realizar esta práctica para ponerla en funcionamiento y realizar pruebas con hardware real, lo cual me parece imprescindible.

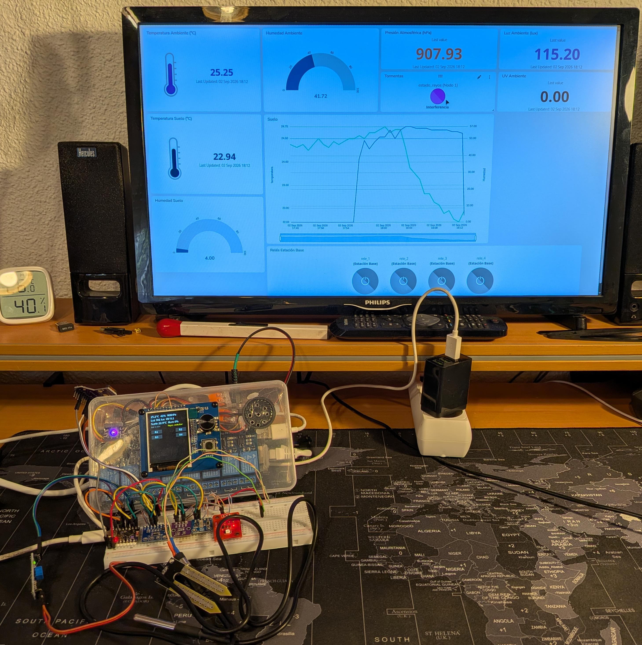
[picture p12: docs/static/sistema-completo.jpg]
Sistema completo con el panel de control de Ubidots


# 2. Nodo solar autónomo

El nodo solar autónomo está compuesto de un ESP32-C3 Supermini de TENSTAR ROBOT[^3] como unidad de procesamiento. Este microcontrolador tiene las siguientes características relevantes para nosotros:

- Procesador: CPU de 32 bits RISC-V con núcleo único, operando a una frecuencia de hasta 160 MHz.
- Memoria: 4 MB de memoria Flash integrada, 400 KB de SRAM y 384 KB de ROM.
- Conectividad: soporte integrado para Wi-Fi (protocolo 802.11 b/g/n en banda de 2.4 GHz) y Bluetooth 5.0 (BLE), con antena cerámica incorporada.
- Interfaces y Pines: 11 GPIOs digitales configurables (usables como PWM) y 4 entradas analógicas (ADC), además de interfaces UART, I2C, SPI e I2S.
- Alimentación y Consumo: se alimenta mediante puerto USB Tipo C (5V) o pines de 3.3V, destacando por un consumo ultra bajo en modo *deep sleep* de aproximadamente 43 µA.

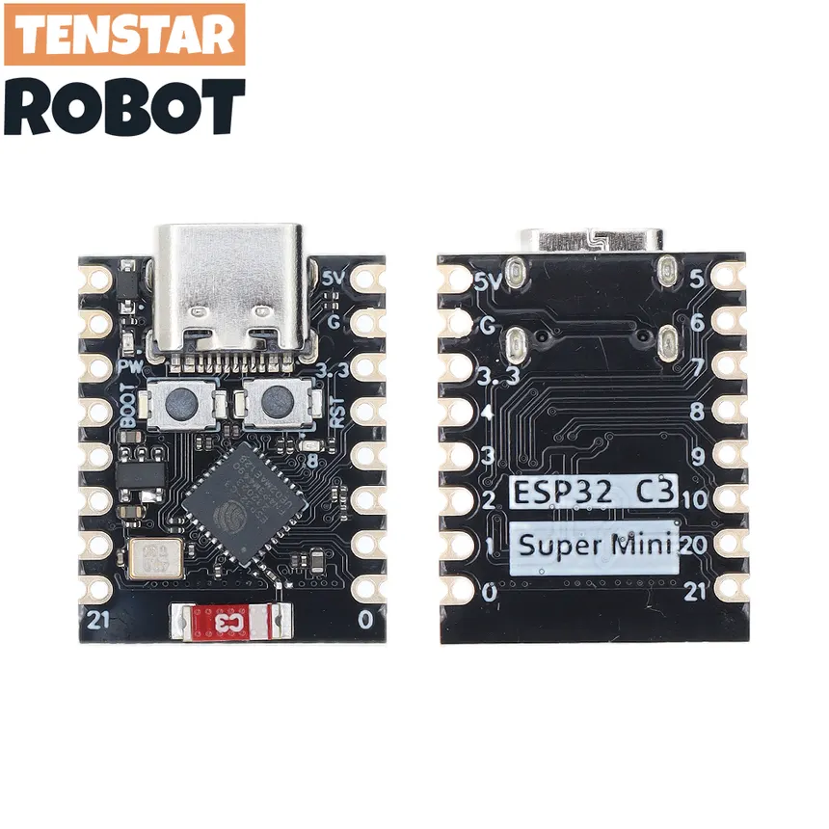
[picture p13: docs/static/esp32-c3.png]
TENSTAR ROBOT ESP32-C3 Super Mini


Usaré para programar la extensión *PlatformIO* de *Visual Studio Code* con el framework *Arduino*, que dispone de muchas librerías ya probadas para los sensores que emplearé.

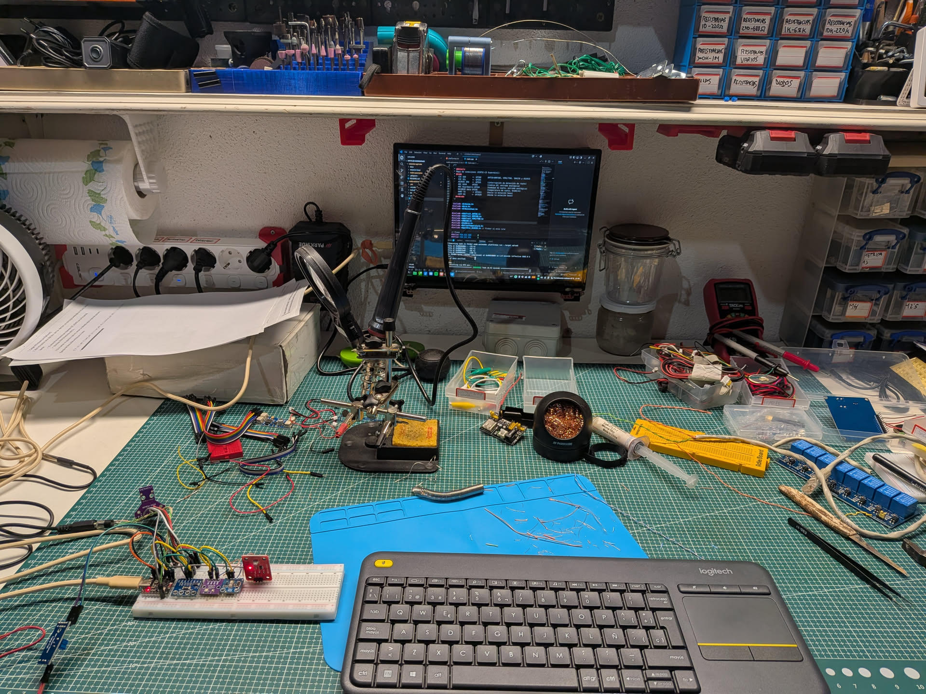
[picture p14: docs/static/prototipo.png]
Desarrollo del prototipo del nodo autónomo


## 2.1. Sensores ambientales

A este microcontrolador conecto los siguientes sensores:

- AHT20+BMP280: mide temperatura, humedad relativa y presión atmosférica ambientales. El módulo que tengo combina ambos sensores y funciona por I2C. Uso las librerías de *Adafruit* para los *AHTX0*[^5] y para el *BMP280*[^6].

- VEML7700: mide la luz ambiental real de forma lineal y con alta precisión y funciona por I2C. Rango de medición de 0 a 120.000 lux, detecta luz visible e IR. Uso la librería de *Adafruit* para el *VEML7700*[^7].

- GUVA-S12SD: calcula el índice UV para luces de longitudes de onda de 240 nm a 370 nm con salida analógica y salida entre 0 y 1 V. Lo leo directamente usando un pin ADC y lo convierto suponiendo que 1 V equivale a un 10 en el índice de radiación ultravioleta.

- AS3935: usado para detectar rayos y estimar la distancia a la tormenta. Puede detectar rayos hasta a 40 km con una precisión de 1 km en 14 pasos. Tiene un pin de alerta que conecto al ESP32-C3 para avisar de descargas en tiempo real mediante el uso de una interrupción. Es sensible a las interferencias electromagnéticas (EMI) de los convertidores DC-DC, pantallas y el propio WiFi/Bluetooth del ESP32-C3 por lo que, idealmente, habría que situarlo en una caja estanca[^9] a cierta distancia del resto de componentes de nuestro nodo autónomo. Se puede conectar usando SPI o I2C, lo conecto usando I2C pese a que dicen que suele funcionar mejor usando SPI para economizar pines del microcontrolador. Uso la librería de *SparkFun*[^8] pese a que mi módulo (etiquetado como CJMCU[^10]) ni se parece al suyo, pero parece funcionar bien. Lo puedo activar usando el cuarzo de un mechero, o acercándolo a los propios relés y activándolos, así detecta a veces incluso un rayo para las pruebas, aunque la mayoría de las veces detecta solo interferencias o ruido, que internamente diferencia de los rayos de verdad usando algoritmos de validación de señal y picos configurables que yo, de momento, no he tocado.

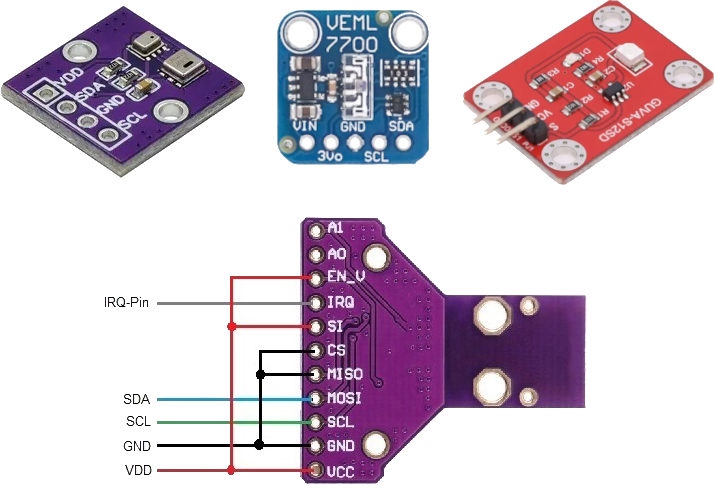
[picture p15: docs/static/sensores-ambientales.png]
Sensores ambientales empleados


## 2.2. Sensores de suelo

- Higrómetro de suelo FC-28: mide la humedad de la tierra usando un sensor simple por variación de conductividad[^11]. La placa de medición, que emplea un comparador LM393, devuelve valores analógicos o una señal alta digital cuando la humedad supera cierto umbral que podemos definir con un potenciómetro. Uso la salida analógica con el ADC de 12 bits del ESP32-C3 para obtener valores entre 0 y 4096. Metiendo el sensor en un vaso de agua calculo un valor de 1800 para 100% de humedad y 4096 para 0%, aunque tal como funciona este sensor sus mediciones solo deberían servirnos para saber si la tierra está húmeda o no, y no tener muy en cuenta el valor que devuelve.

- Sonda Sumergible DS18B20: mide la temperatura, en principio está diseñado para ser usado en el agua (yo los he usado en acuarios), pero aquí lo emplearemos enterrado en la tierra. Usa el protocolo *OneWire*, empleo la librería de Paul Stoffregen[^12], pongo una resistencia de *pull-up* de 4,7 kΩ (si alargamos el cable habría que bajar el valor) entre VCC y DATA y lo leo con la librería de Miles Burton[^13].

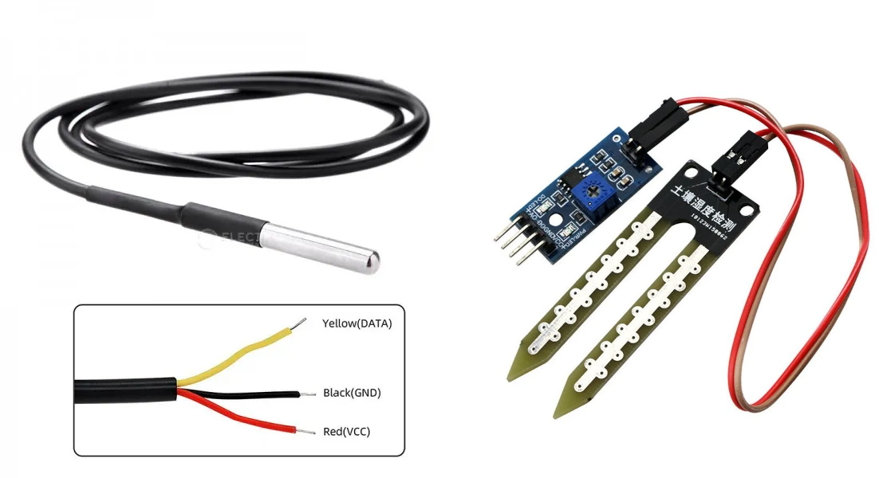
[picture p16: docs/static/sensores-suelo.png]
Sensores de suelo


## 2.3. Comunicación con la estación base

Los datos se envían por serie cada 5 segundos a la estación base a través del puerto USB, que también nos sirve de alimentación, en formato JSON usando la librería *ArduinoJSON*[^4]. Este es el formato empleado:

```json
{"t":14107,"amb":{"temp_amb":25.30,"hum_amb":42.0,"presion_hpa":905.24,"luz_lux":117.5,"uv":6},
 "suelo":{"temp_suelo":24.8,"hum_suelo":4095},
 "energia":{"v_bat":0,"i_ma":0,"p_mw":0},
 "rayos":{"estado":"ok"}}
```

| Campo | Tipo | Descripción |
|---|---|---|
| `t` | int | tiempo de actividad del nodo en segundos (`millis()/1000`) |
| `amb.temp_amb` | float °C | temperatura ambiente (AHT20) |
| `amb.hum_amb` | float % | humedad relativa ambiente (AHT20) |
| `amb.presion_hpa` | float hPa | presión atmosférica (BMP280) |
| `amb.luz_lux` | float lux | iluminación (VEML7700) |
| `amb.uv` | int 0-4095 | ADC raw del GUVA-S12SD |
| `suelo.temp_suelo` | float °C | temperatura del suelo (DS18B20) |
| `suelo.hum_suelo` | int 0-4095 | ADC raw del higrómetro |
| `energia.v_bat` | float V | no usado (INA226) |
| `energia.i_ma` | float mA | no usado (INA226) |
| `energia.p_mw` | float mW | no usado (INA226) |
| `rayos.estado` | string | `ok` \| `disturber` \| `rayo` \| `ruido` \| `desconocido` (AS3935) |
| `rayos.dist_km` | int km | distancia al frente de tormenta (solo si `estado`=`rayo`) |

## 2.4. Alimentación

Alimento todo desde el ESP32-C3 alimentado a su vez por USB desde la estación base. Todos los sensores funcionan a 3,3 V sacados del regulador interno del ESP32-C3.

He dejado conectado un módulo con un INA226 para medir voltajes y corrientes de alimentación por I2C (usando la librería de Rob Tillaart[^14]) porque mi idea inicial era usar un panel solar y una batería para alimentar el nodo autónomo, pero al establecer comunicación con la estación base usando USB, que trae su propia alimentación, me iba a complicar demasiado. La tarea de hacer el nodo autónomo realmente autosuficiente la dejo para la práctica final de la asignatura Comunicaciones Inalámbricas y Protocolos para el Internet de las Cosas.

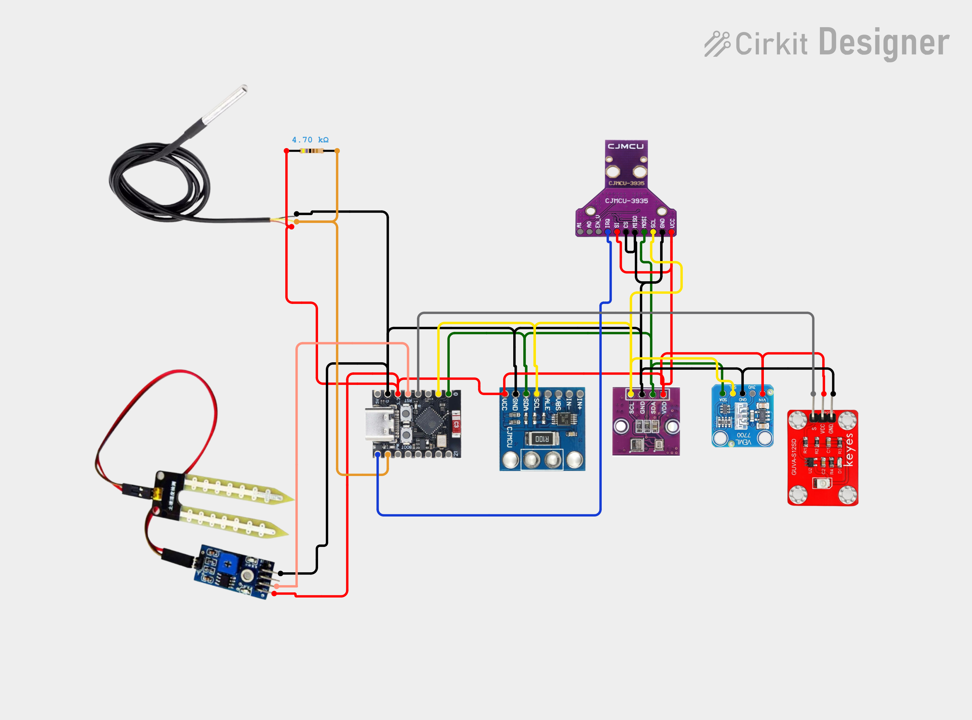
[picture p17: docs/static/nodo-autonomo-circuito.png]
Esquema de conexiones del nodo autónomo (Cirkit Designer)


# 3. Estación base

Usaré mi vieja y fiable Raspberry Pi 1 Model B Rev1.0 que empleé para una de las prácticas de la asignatura Comunicaciones Inalámbricas y Protocolos para el Internet de las Cosas. Esta versión tiene las siguientes características relevantes:
- Procesador: Broadcom BCM2835 con núcleo único ARM1176JZF-S a 700 MHz.
- Memoria: 256 MB SDRAM (compartida entre CPU y GPU).
- Red: puerto Ethernet RJ45 10/100 Mbps. Conectado a mi red local.
- USB: 2 puertos USB 2.0. Puentee los fusibles poliméricos integrados para no limitar la corriente con la que se alimentan los dispositivos USB.
- Almacenamiento: tarjeta MicroSD de 64GB.
- GPIO: cabecera de 26 pines (8 pines GPIO, más pines para I2C, SPI y UART). Los pines I2S no están completos como veremos más adelante.
- Alimentación: entrada Micro USB, uso una fuente de 5V 3A.

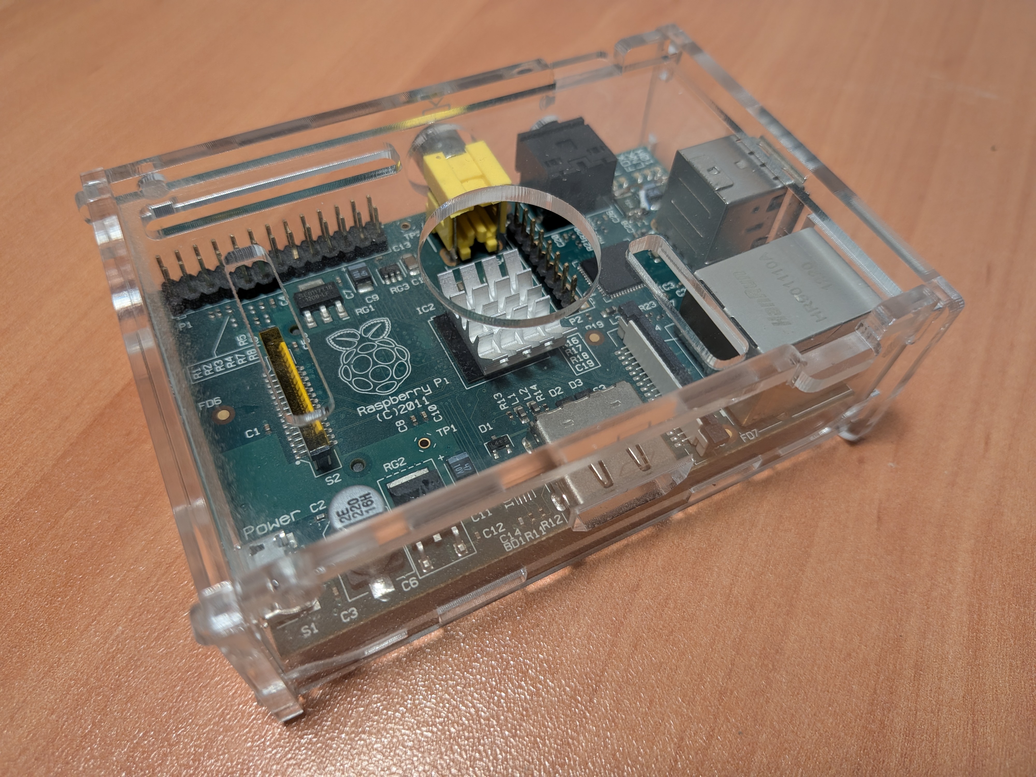
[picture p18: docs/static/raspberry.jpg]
Mi Raspberry Pi 1 Model B Rev1.0


## 3.1. Periféricos

- Pantalla: la empleo para mostrar los datos recibidos del nodo, incluyendo alertas y controlar los relés conectados a la estación base. Uso un módulo con una pantalla de 2 pulgadas con una controladora ST7789 y 320x240 px de resolución con codificador rotatorio EC11 y un botón extra integrados (en la práctica 4 botones). La pantalla se conecta por SPI usando la librería *luma.lcd*[^19] y se dibuja usando *Pillow*[^21]. La pantalla funciona a 3,3 V sacados de la cabecera de la Raspberry Pi.

- LED de estado: empleado para indicar el estado del sistema. Uso un WS2812B conectado directamente. Tuve un conflicto con la salida analógica de audio al usar el pin `GPIO18` que me costó depurar: el LED no funcionaba en mi programa pero sí en los que lo probaba solo, y el audio al tratar de hacer funcionar los dos a la vez sonaba mal. Eso se debía a que ambos usan PWM y se pisaban; cambiando el LED al pin `GPIO21`, que funciona usando PCM y es compatible con la librería usada[^15], lo solucioné. El LED lo alimento a 5V, aunque la lógica de la Raspberry Pi funciona a 3,3 V, no parece que dé problemas.

- Amplificador y altavoz: usados para emitir alertas y avisos. Al principio pensé en usar un amplificador digital, concretamente un módulo con un MAX98357, conectado por I2S a los GPIO para obtener la mejor calidad de sonido. No obstante, al ir a conectarlo me di cuenta de que esta versión de la Raspberry Pi, con 26 pines en la cabecera y anterior a la revisión con la cabecera extra, no expone todos los pines necesarios para usar I2S, con lo que finalmente empleo un amplificador analógico, un módulo con un PAM8302A, conectado al jack de 3,5 mm y a un pequeño altavoz de 8 Ω y 0,5 W, con lo que me es suficiente con alimentarlo a 3,3 V.

- Relés: uso también un módulo con 8 relés a 5V para simular la apertura de válvulas de riego y la activación de otros sistemas. La lógica de control de los relés la tengo funcionando a 3,3 V mientras que las bobinas están alimentadas a 5V, valor para el que están diseñadas. Solo conecto 4 de los relés, más que suficientes para realizar pruebas, y uso sus LEDs de estado para comprobar que funcionan correctamente.

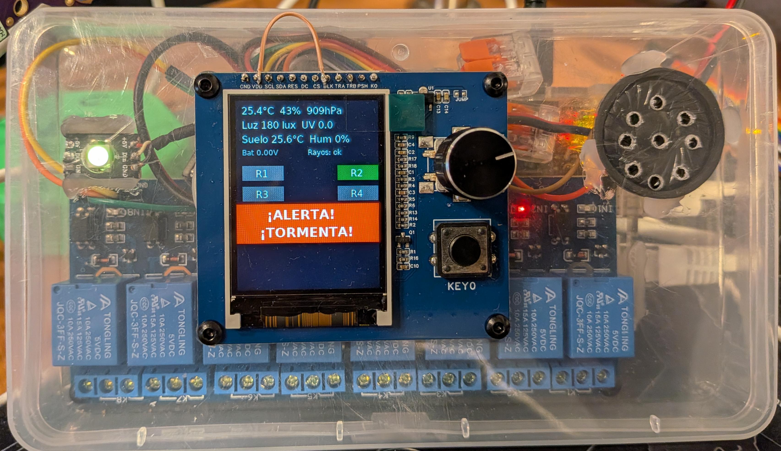
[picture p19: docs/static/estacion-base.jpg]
La estación base ya montada. La Raspberry Pi está en la parte posterior


## 3.2. Alimentación

La estación base, y todos sus periféricos, se alimentan a través de una fuente de 5V 3A conectada a la toma de alimentación de la Raspberry Pi. Tengo que arrancar la estación base con el nodo autónomo conectado porque si lo conecto después la Raspberry Pi se bloquea por el pico de potencia requerido, no es un gran inconveniente.

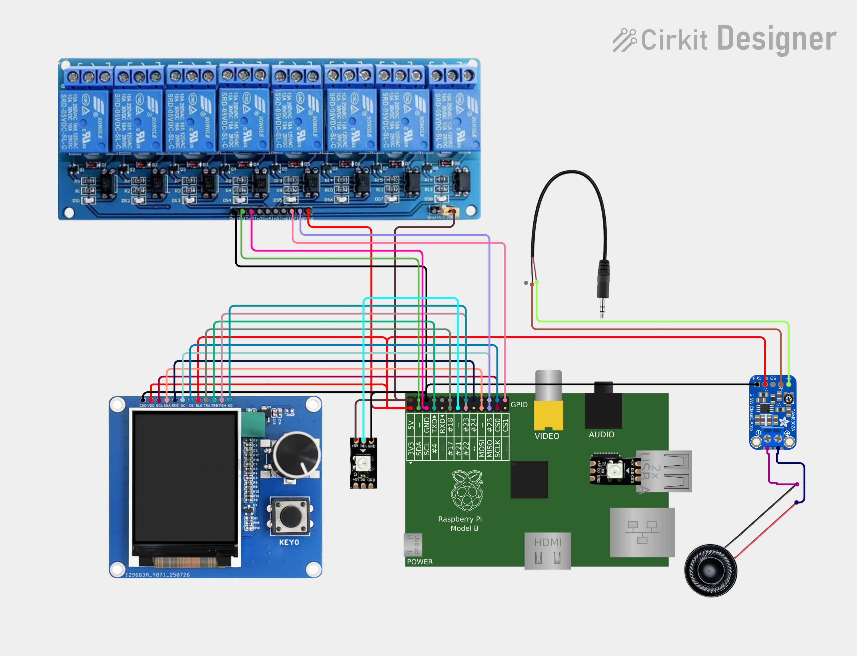
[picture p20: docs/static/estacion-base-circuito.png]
Esquema de conexiones de la estación base (Cirkit Designer)


## 3.3. Configuración inicial

Uso *DietPi*[^1] como imagen para la Raspberry Pi dado que es una imagen mínima y tiene mejor rendimiento (el sistema en funcionamiento consume menos de 55 MB de RAM) que una imagen de *Raspbian* completa.

Activo el audio instalando *ALSA* y configurando la tarjeta de sonido para que use la interna de la Raspberry Pi, también activo SPI. Todo se hace desde la consola usando `dietpi-config`, la herramienta de configuración de DietPi. Instalo también las dependencias de Python para que funcionen los GPIO.

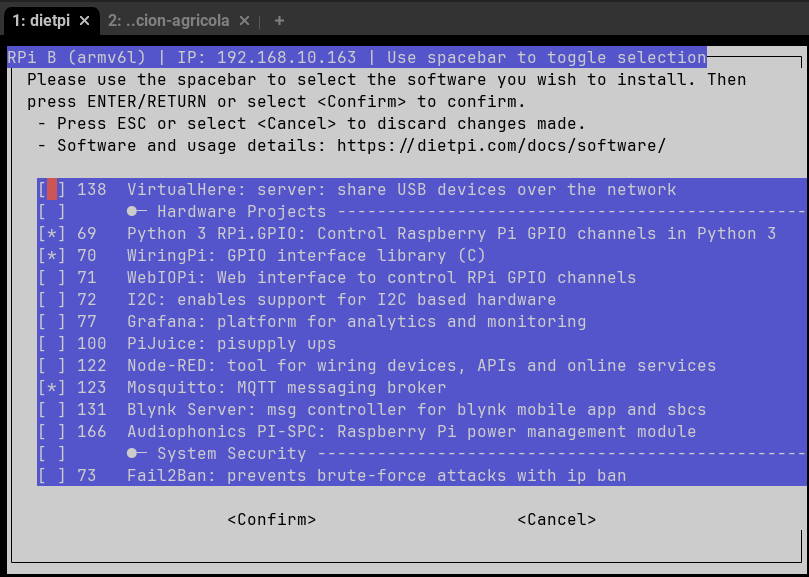
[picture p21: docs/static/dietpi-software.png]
Software disponible en DietPi para interacción con hardware


También son necesarios los paquetes adicionales `libjpeg-dev libtiff6 libopenjp2-7 libxcb1 libfreetype6` para que funcione la pantalla y el paquete `espeak-ng` para los avisos hablados.

## 3.4. Programa de monitorización y control

El programa de la estación base, escrito en Python y organizado como paquete instalable, recibe del nodo por el puerto USB el JSON con los datos de los sensores y muestra por la pantalla los valores obtenidos del nodo autónomo y permite la activación de los relés durante una duración de tiempo variable. Uso GitHub[^22] para sincronizar mi repositorio local, después de clonarlo e instalar las dependencias del sistema podemos instalar el programa usando:

```bash
# desde estacion-base/
python3 -m venv ~/venvs/estacion
source ~/venvs/estacion/bin/activate
pip install --upgrade pip
pip install -e .
cp .env.example .env    # rellenar los tokens
sudo ~/venvs/estacion/bin/python -m estacion_base
```
Como se ve necesitamos usar `sudo` para ejecutar el programa debido al uso de DMA por la librería *neopixel* que controla el WS2812B; no es lo mejor pero las alternativas que he visto no me convencían, al menos nos quitamos de añadir nuestro usuario a los grupos `gpio`, `spi`, `audio` y `dialout` para tener permisos para usar el resto de periféricos.

Uso un fichero de configuración `config.py` con todas las constantes y los tokens de acceso a *Ubidots* en un fichero `.env` fuera del repositorio. He usado hilos independientes para varias tareas (lectura del nodo, entrada, comunicación con *Ubidots*, reproducción de audio y dibujo de la pantalla) para evitar bloqueos que surgieron durante el desarrollo y dar mayor fluidez al programa.

El programa se controla usando el botón del encoder en pulsación corta para abrir el menú de selección de relés que se pueden cambiar moviendo el encoder y activar usando el propio botón integrado. El botón externo `KEY0` se usa para volver de los menús y apagar la alerta que se emite cuando se detecta un rayo, mientras que una pulsación prolongada de este botón permite además apagar todos los relés y volver a la pantalla principal.

El LED WS2812B indica el estado del sistema siguiendo esta tabla de colores:
  - Verde: funcionamiento normal.
  - Amarillo: tierra seca.
  - Violeta: interferencia detectada por el sensor de rayos.
  - Azul: riego en proceso.
  - Rojo: rayo detectado.

Para las alertas y avisos al principio usé un tono de 880 Hz generado usando `speaker-test -t sine -f 880 -c 1 -l 1`, pero como quería también aprovechar el sonido para más cosas, al final he acabado usando *espeak-ng*[^23] a través de *py-espeak-ng*[^24] para hacer *text-to-speech* y emitir también avisos cuando se activan y desactivan los relés. El tono se ha dejado como respaldo si no funciona la voz. Me ha sorprendido lo bien que funciona este programa en una SBC tan limitada como mi Raspberry Pi.

Las automatizaciones de prueba residen en la estación base para ser independientes de internet y tener menor latencia. Ahora hay una muy básica que enciende el relé 1 durante 10 segundos cuando la humedad baja de un nivel preprogramado y no se puede repetir hasta 10 minutos después y otra que activa una alerta cuando detectamos un rayo a menos de 15 km.

Almaceno también de forma local, en la carpeta `data`, un fichero de log por cada arranque del programa con los datos del nodo que vamos recibiendo y el estado de los relés de la estación base.

El siguiente diagrama muestra la arquitectura del programa y el flujo de datos:

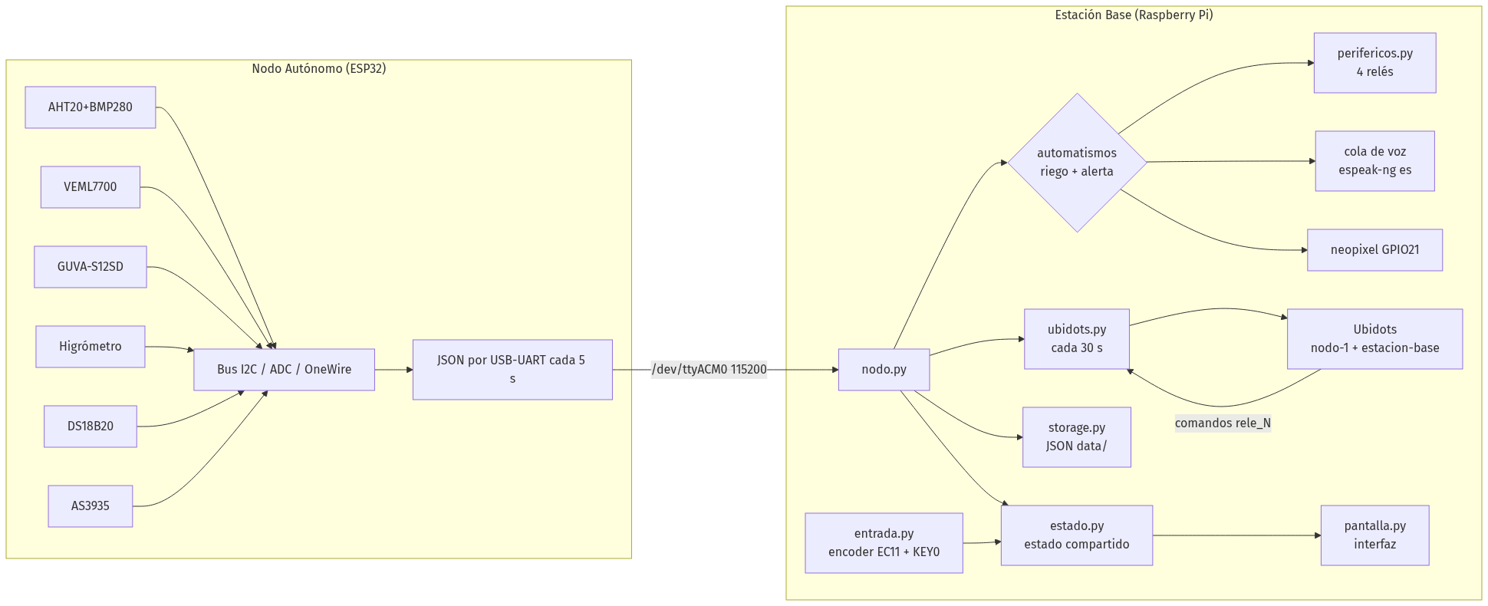
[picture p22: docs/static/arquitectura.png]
Arquitectura del programa y flujo de datos


# 4. Plataforma IoT en la nube: Ubidots

Elijo *Ubidots STEM*[^20] por su sencillez y porque creo que su cuenta gratuita cubre mis requisitos pese a estar limitada. El panel de control que uso muestra todos los datos del nodo además del estado de los relés y permite su accionamiento remoto.

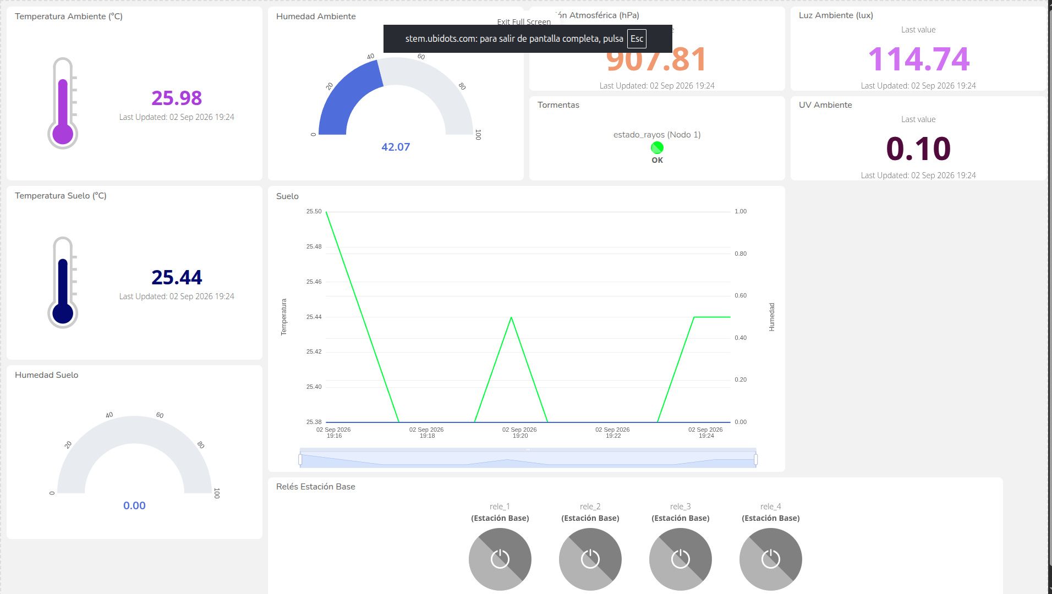
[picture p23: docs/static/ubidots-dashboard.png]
Panel de control de Ubidots


Envío los datos desde la estación base usando su API por HTTP POST[^25] cada 30 segundos. Leo también el estado de los relés desde *Ubidots* para poder activarlos a distancia.

Separo los datos que envío en dos dispositivos: `nodo-1` con los sensores y `estacion-base` con los relés.

`nodo-1`:

```json
{"temp_amb":25.30,"hum_amb":42.0,"presion_hpa":905.2,"luz_lux":384.5,
 "uv_index":1,"temp_suelo":22.8,"hum_suelo":4095,"hum_suelo_pct":0,
 "v_bat":0,"i_ma":0,"p_mw":0,"estado_rayos":0,"dist_km":0}
```

- `uv_index`: índice UV ya convertido, de 0 a 10.
- `hum_suelo_pct`: humedad ya convertida, de 0 a 100%.
- `estado_rayos`: numérico **0** ok, **1** disturber, **2** rayo, **3** ruido. Tuve que convertirlo porque *Ubidots* al parecer solo acepta números, de todas formas es mejor, ahorramos datos.

`estacion-base`:

```json
{"rele_1":1,"rele_2":0,"rele_3":0,"rele_4":0}
```

- `rele_N`: 0/1 con el estado real de cada relé. Señalar que se envía 0 para apagado y 1 para encendido, al contrario de como funcionan realmente (activos en LOW).

Tuve algún problema de rebote con los relés al compartir en *Ubidots* su estado y su accionamiento, y de hecho su funcionamiento sigue sin ser perfecto, pero era más una prueba de concepto que otra cosa puesto que la intención es controlar los relés directamente desde la estación base, ya sea usando automatizaciones o su control manual integrado. Se han implementado mecanismos de control de errores (404, 429) en la transmisión también con el fin de evitar el uso excesivo de la API proporcionada.

# 5. Conclusiones y mejoras futuras

Esta práctica me ha servido para poner en práctica los conocimientos adquiridos durante el curso y sortear limitaciones de hardware, también para tratar de realizar un código más limpio y tener en cuenta aspectos como la limpieza de los pines GPIO y dispositivos al salir que a veces no tenemos en cuenta. Tampoco me ha supuesto un desafío excesivo, si no contamos con el tiempo invertido en cosas prescindibles como mejorar la interfaz gráfica de la pantalla empleada o el uso de los relés a distancia desde Ubidots, dado que me dedico a la programación de sistemas embebidos (fundamentalmente STM32 en C puro). Considero útil también el descubrimiento de Ubidots y su facilidad de uso a la hora de visualizar datos.

Hay muchas mejoras que se pueden implementar en el sistema, algunas de ellas se llevarán a cabo en la práctica final de la asignatura Comunicaciones Inalámbricas y Protocolos para el Internet de las Cosas. Entre ellas destaco:

- Uso de otro protocolo de comunicaciones que sea inalámbrico, el nodo autónomo debe estar separado de la estación base.
- Uso de una batería y panel solar en el nodo autónomo para alimentarlo.
- Emplear MQTT para las comunicaciones entre nodo autónomo y estación base y con *Ubidots*.
- Hacer el sistema realmente escalable para que una sola estación base pueda soportar múltiples nodos autónomos que se conectarían fácilmente sin tocar el código.
- Realizar cajas impresas en 3D diseñadas a medida tanto para el nodo autónomo, separando los sensores que necesitan estar en el exterior con sus propias carcasas, como para la estación base.
- Usar *mosfets*, como el Si2312, para apagar los sensores cuando no se utilizan en el nodo autónomo y así ahorrar energía.
- Añadir al nodo autónomo un sensor de pluviometría para registrar el nivel de lluvia y un anemómetro y veleta para registrar la velocidad y dirección del viento.
- Usar un ESP32-C6 reemplazando al ESP32-C3 empleado por ser la última versión de esta gama y tener mejor conectividad, aunque en principio nosotros no emplearemos ni WiFi ni Bluetooth para comunicarnos.
- Firmware del nodo autónomo actualizable vía *OTA*, uso de *secure boot*.
- Usar mejores sensores de suelo ya que los empleados se corroen fácilmente como he comprobado.
- Crear PCBs para todo el sistema, especialmente para el nodo autónomo, y así reducir su tamaño y coste.

[^1]: DietPi - Lightweight justice for your SBC!. Disponible en: <https://dietpi.com/>. Accedido el 12/8/2026.
[^2]: Viveros Integrales El Ejidillo Disponible en: <https://ejidillo.com/>. Accedido el 12/8/2026.
[^3]: TENSTAR ROBOT - Placa de desarrollo TENSTAR ROBOT ESP32 C3 SuperMini Disponible en: <https://tenstar.pro/robot-esp32-c3-supermini/>. Accedido el 24/8/2026.
[^4]: GitHub - ArduinoJson. Disponible en: <https://github.com/bblanchon/ArduinoJson>. Accedido el 27/8/2026.
[^5]: GitHub - Adafruit AHTX0 (AHT10 & AHT20). Disponible en: <https://github.com/adafruit/Adafruit_AHTX0>. Accedido el 27/8/2026.
[^6]: GitHub - Adafruit BMP280 Driver (Barometric Pressure Sensor). Disponible en: <https://github.com/adafruit/adafruit_bmp280_library>. Accedido el 27/8/2026.
[^7]: GitHub - Adafruit_VEML7700. Disponible en: <https://github.com/adafruit/Adafruit_VEML7700>. Accedido el 27/8/2026.
[^8]: GitHub - SparkFun AS3935 Lightning Detector Arduino Library. Disponible en: <https://github.com/sparkfun/SparkFun_AS3935_Lightning_Detector_Arduino_Library>. Accedido el 27/8/2026.
[^9]: Garry's blog - Ben Franklin and DIY Lightning Detection using a AS3935 Lightning Sensor. Disponible en: <https://garrysblog.com/2025/07/23/ben-franklin-and-diy-lightning-detection-using-a-as3935-lightning-sensor/>. Accedido el 27/8/2026.
[^10]: Tasmota - AS3935 Franklin Lightning sensor. Disponible en: <https://tasmota.github.io/docs/AS3935/#cjmcu-board>. Accedido el 27/8/2026.
[^11]: DitecnoMakers - Medir la humedad de la tierra con Arduino y un Higrómetro FC-28. Disponible en: <https://tasmota.github.io/docs/AS3935/#cjmcu-board>. Accedido el 27/8/2026.
[^12]: PJRC - OneWire Arduino Library, connecting 1-wire devices (DS18S20, etc) to Teensy. Disponible en: <https://tasmota.github.io/docs/AS3935/#cjmcu-board>. Accedido el 27/8/2026.
[^13]: GitHub - Arduino Temperature Control Library. Disponible en: <https://github.com/milesburton/Arduino-Temperature-Control-Library>. Accedido el 27/8/2026.
[^14]: GitHub - Arduino library for the INA226 power sensor. Disponible en: <https://github.com/RobTillaart/INA226>. Accedido el 27/8/2026.
[^15]: Adafruit - Adafruit NeoPixel Überguide. Disponible en: <https://learn.adafruit.com/adafruit-neopixel-uberguide/python-circuitpython>. Accedido el 2/9/2026.
[^16]: UPRtek - El Espectro UVA en la Agricultura de Interior: Mejora de la calidad y el rendimiento de los cultivos con iluminación UV-A. Disponible en: <https://www.uprtek.com/es/blogs/indoor-agriculture-leveraging-the-power-of-uva-spectrum>. Accedido el 2/9/2026.
[^17]: Hydro Environment - Guía Práctica: La Importancia de la Luz en el Cultivo. Disponible en: <https://hydroenv.com.mx/guia-practica-la-importancia-de-la-luz-en-el-cultivo/>. Accedido el 2/9/2026.
[^18]: EOS Data Analytics - Temperatura Del Suelo Para La Siembra Y El Cultivo. Disponible en: <https://eos.com/es/blog/temperatura-del-suelo/>. Accedido el 2/9/2026.
[^19]: PyPi - luma.lcd. Disponible en: <https://pypi.org/project/luma.lcd/>. Accedido el 2/9/2026.
[^20]: Ubidots - STEM. Disponible en: <https://ubidots.com/stem>. Accedido el 2/9/2026.
[^21]: Pillow - Documentation. Disponible en: <https://pillow.readthedocs.io/en/stable/>. Accedido el 2/9/2026.
[^22]: GitHub - Estación Agrícola Autónoma. Disponible en: <https://github.com/alexprovencio/estacion-agricola>. Accedido el 2/9/2026.
[^23]: GitHub - eSpeak NG Text-to-Speech. Disponible en: <https://github.com/espeak-ng/espeak-ng>. Accedido el 2/9/2026.
[^24]: GitHub - py-espeak-ng. Disponible en: <https://github.com/gooofy/py-espeak-ng>. Accedido el 2/9/2026.
[^25]: Docs Ubidots - HTTP Overview. Disponible en: <https://docs.ubidots.com/v1.6/reference/http>. Accedido el 2/9/2026.

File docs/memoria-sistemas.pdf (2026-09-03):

# UNIVERSIDAD NACIONAL DE EDUCACIÓN A DISTANCIA

# Escuela Técnica Superior de Ingenieros Industriales

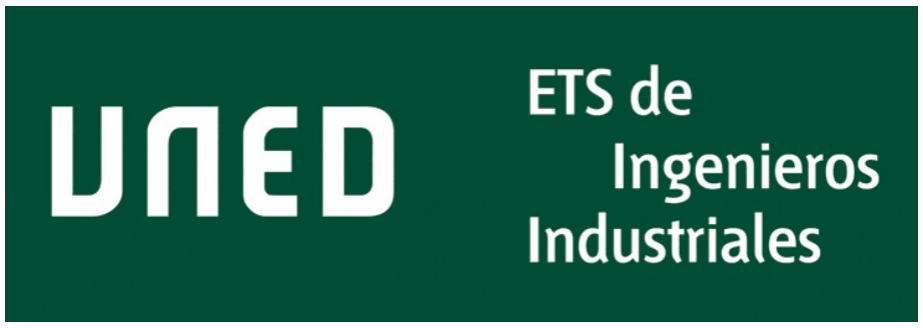
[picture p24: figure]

# Micromáster en Internet de las Cosas

# Trabajo Final a Distancia SISTEMAS DIGITALES PARA EL INTERNET DE LAS COSAS

## Alejandro Provencio Sanz

## aprovenci9@alumno.uned.es

3/9/2026

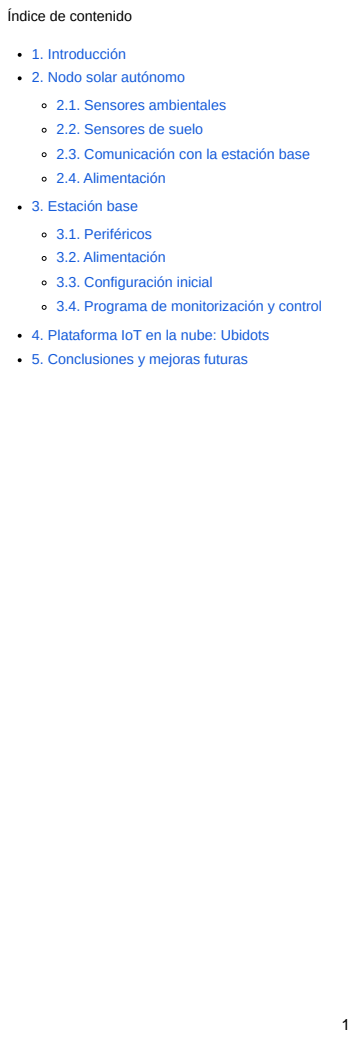
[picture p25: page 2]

Índice de contenido

1. Introducción
2. Nodo solar autónomo
2.1. Sensores ambientales
2.2. Sensores de suelo
2.3. Comunicación con la estación base
2.4. Alimentación
3. Estación base
3.1. Periféricos
3.2. Alimentación
3.3. Configuración inicial
3.4. Programa de monitorización y control
4. Plataforma IoT en la nube: Ubidots
5. Conclusiones y mejoras futuras

## 1. Introducción

La idea para este trabajo es realizar un sistema completo de mediciones ambientales y del suelo para agricultura inteligente. En principio lo he diseñado para usarlo en huertas, viveros, invernaderos o cultivos extensos, fundamentalmente de regadío. Como ejemplo de empresa de mi zona que podría emplearlo están los viveros El Ejidillo

[1] en Valdesimonte, Segovia, con un terrero de cultivo de 65 hectáreas.


Fig. 1: Fotografía de los viveros El Ejidillo

El sistema realizará las siguientes mediciones mediante un nodo autónomo instalado in situ:

Temperatura ambiente: para detectar estrés térmico por calor o frío excesivos y predecir heladas. Humedad relativa del aire: podemos anticipar la aparición de enfermedades debidas a la alta humedad y, combinado con la temperatura, calcular la transpiración de las plantas con el fin de dimensionar el riego.
Presión atmosférica: ayuda a la previsión meteorológica local, por ejemplo, una rápida caída de la presión puede indicar lluvia, viento o una tormenta.
Iluminación incluyendo IR: ayuda a detectar exceso o déficit de luz en las plantas, lo que puede alterar su crecimiento. En un invernadero o cultivo bajo cubierta serviría para ajustar la iluminación artificial.

[2]
Índice UV: afecta a la calidad, sabor y conservación de los frutos, además, lo podemos usar para proteger a los operarios los días de mayor incidencia o regular el uso de lámparas UVA en cultivos de interior.

[3]
Proximidad de tormentas: nos puede servir para recolectar los frutos antes de la llegada de la tormenta evitando su deterioro a causa del granizo o la lluvia excesiva, también a preparar nuestros cultivos ante la tormenta, y puede evitar gastos innecesarios derivados de la aplicación de fitosanitarios que se desperdiciarían si se aplican justo antes de la lluvia.
Temperatura del suelo: nos ayuda a encontrar el momento óptimo para la siembra, puede servirnos para calcular la disponibilidad de nutrientes y detectar riesgos de heladas.

[4]
Humedad del suelo: fundamentalmente nos indica cuando regar, evitando riego en exceso o defecto, ahorrando agua y detectando problemas de drenaje.
Todas estas mediciones serán efectuadas por un nodo autónomo (ESP32-C3 SuperMini) que se instalaría en la propia huerta y cuyos datos se enviarán a una estación base (Raspberry Pi 1 Model B) para su procesamiento y envío a una plataforma IoT en la nube (Ubidots) para su análisis.

La estación base dispondrá a su vez de una pantalla para visualización de los datos y/o alertas del sistema, botones que controlarán una serie de relés que, hipotéticamente, podrían activar bombas de riego, luces... y un altavoz que emitirá alertas (por ejemplo ante la proximidad de una tormenta) y avisos.

El sistema se diseñará, en esta primera etapa, con una conexión simple por el puerto USB entre el nodo autónomo y la estación base, con la idea de mejorar el sistema de comunicaciones entre ambos en la práctica final de la asignatura Comunicaciones Inalámbricas y Protocolos para el Internet de las Cosas. El diseño se ha hecho pensando que sea fácilmente escalable para que una sola estación base pueda gestionar múltiples nodos autónomos, aunque no lo he probado ni optimizado para ese caso.

Cabe señalar que he decidido aprovechar buena parte del hardware que ya tenía para realizar esta práctica para ponerla en funcionamiento y realizar pruebas con hardware real, lo cual me parece imprescindible.


Fig. 2: Sistema completo con el panel de control de Ubidots

## 2. Nodo solar autónomo

El nodo solar autónomo está compuesto de un ESP32-C3 Supermini de TENSTAR ROBOT

[5] como
unidad de procesamiento. Este microcontrolador tiene las siguientes características relevantes para nosotros:

Procesador: CPU de 32 bits RISC-V con núcleo único, operando a una frecuencia de hasta 160 MHz. Memoria: 4 MB de memoria Flash integrada, 400 KB de SRAM y 384 KB de ROM.

Conectividad: soporte integrado para Wi-Fi (protocolo 802.11 b/g/n en banda de 2.4 GHz) y Bluetooth 5.0 (BLE), con antena cerámica incorporada.
Interfaces y Pines: 11 GPIOs digitales configurables (usables como PWM) y 4 entradas analógicas (ADC), además de interfaces UART, I2C, SPI e I2S.
Alimentación y Consumo: se alimenta mediante puerto USB Tipo C (5V) o pines de 3.3V, destacando por un consumo ultra bajo en modo deep sleep de aproximadamente 43 µA.


Fig. 3: TENSTAR ROBOT ESP32-C3 Super Mini

Usaré para programar la extensión PlatformIO de Visual Studio Code con el framework Arduino, que dispone de muchas librerías ya probadas para los sensores que emplearé.


Fig. 4: Desarrollo del prototipo del nodo autónomo

## 2.1. Sensores ambientales

A este microcontrolador conecto los siguientes sensores:

AHT20+BMP280: mide temperatura, humedad relativa y presión atmosférica ambientales. El módulo que tengo combina ambos sensores y funciona por I2C. Uso las librerías de Adafruit para los
AHTX0
[6] y para el BMP280

[7]
VEML7700: mide la luz ambiental real de forma lineal y con alta precisión y funciona por I2C. Rango de medición de 0 a 120.000 lux, detecta luz visible e IR. Uso la librería de Adafruit para el
VEML7700

[8]

GUVA-S12SD: calcula el índice UV para luces de longitudes de onda de 240 nm a 370 nm con salida analógica y salida entre 0 y 1 V. Lo leo directamente usando un pin ADC y lo convierto suponiendo que 1 V equivale a un 10 en el índice de radiación ultravioleta.
AS3935: usado para detectar rayos y estimar la distancia a la tormenta. Puede detectar rayos hasta a 40 km con una precisión de 1 km en 14 pasos. Tiene un pin de alerta que conecto al ESP32-C3 para avisar de descargas en tiempo real mediante el uso de una interrupción. Es sensible a las interferencias electromagnéticas (EMI) de los convertidores DC-DC, pantallas y el propio WiFi/Bluetooth del ESP32-C3 por lo que, idealmente, habría que situarlo en una caja estanca
[9] a
cierta distancia del resto de componentes de nuestro nodo autónomo. Se puede conectar usando SPI o I2C, lo conecto usando I2C pese a que dicen que suele funcionar mejor usando SPI para economizar pines del microcontrolador. Uso la librería de SparkFun
[10] pese a que mi módulo
(etiquetado como CJMCU

[11]
) ni se parece al suyo, pero parece funcionar bien. Lo puedo activar usando el cuarzo de un mechero, o acercándolo a los propios relés y activándolos, así detecta a veces incluso un rayo para las pruebas, aunque la mayoría de las veces detecta solo interferencias o ruido, que internamente diferencia de los rayos de verdad usando algoritmos de validación de señal y picos configurables que yo, de momento, no he tocado.


Fig. 5: Sensores ambientales empleados

## 2.2. Sensores de suelo

Higómetro de suelo FC-28: mide la humedad de la tierra usando un sensor simple por variación de conductividad

[12]
. La placa de medición, que emplea un comparador LM393, devuelve valores analógicos o una señal alta digital cuando la humedad supera cierto umbral que podemos definir con un potenciómetro. Uso la salida analógica con el ADC de 12 bits del ESP32-C3 para obtener valores entre 0 y 4096. Metiendo el sensor en un vaso de agua calculo un valor de 1800 para 100% de humedad y 4096 para 0%, aunque tal como funciona este sensor sus mediciones solo deberían servirnos para saber si la tierra está húmeda o no, y no tener muy en cuenta el valor que devuelve. Sonda Sumergible DS18B20: mide la temperatura, en principio está diseñado para ser usado en el agua (yo los he usado en acuarios), pero aquí lo emplearemos enterrado en la tierra. Usa el protocolo OneWire, empleo la librería de Paul Stoffregen

[13]
, pongo una resistencia de pull-up de 4,7 kΩ (si alargamos el cable habría que bajar el valor) entre VCC y DATA y lo leo con la librería de Miles Burton

[14]


Fig. 6: Sensores de suelo

## 2.3. Comunicación con la estación base

Los datos se envían por serie cada 5 segundos a la estación base a través del puerto USB, que también nos sirve de alimentación, en formato JSON usando la librería ArduinoJSON

[15]
. Este es el formato
empleado:

{"t":14107,"amb":
{"temp_amb":25.30,"hum_amb":42.0,"presion_hpa":905.24,"luz_lux":117.5,"uv":6}, "suelo":{"temp_suelo":24.8,"hum_suelo":4095}, "energia":{"v_bat":0,"i_ma":0,"p_mw":0},
"rayos":{"estado":"ok"}}
Campo | Tipo | Descripción
t | int | tiempo de actividad del nodo en segundos ( millis()/1000 )
amb.temp_amb | float °C | temperatura ambiente (AHT20)
amb.hum_amb | float % | humedad relativa ambiente (AHT20)
amb.presion_hpa | float hPa | presión atmosférica (BMP280)
amb.luz_lux | float lux | iluminación (VEML7700)
amb.uv | int 0-4095 | ADC raw del GUVA-S12SD
suelo.temp_suelo | float °C | temperatura del suelo (DS18B20)
suelo.hum_suelo | int 0-4095 | ADC raw del higrómetro
energia.v_bat | float V | no usado (INA226)
energia.i_ma | float mA | no usado (INA226)
energia.p_mw | float mW | no usado (INA226)
rayos.estado | string | ok | disturber | rayo | ruido | desconocido (AS3935)
rayos.dist_km | int km | distancia al frente de tormenta (solo si estado = rayo )

## 2.4. Alimentación

Alimento todo desde el ESP32-C3 alimentado a su vez por USB desde la estación base. Todos los sensores funcionan a 3,3 V sacados del regulador interno del ESP32-C3.

He dejado conectado un módulo con un INA226 para medir voltajes y corrientes de alimentación por I2C (usando la librería de Rob Tillaart

[16]
) porque mi idea inicial era usar un panel solar y una batería para alimentar el nodo autónomo, pero al establecer comunicación con la estación base usando USB, que trae su propia alimentación, me iba a complicar demasiado. La tarea de hacer el nodo autónomo realmente autosuficiente la dejo para la práctica final de la asignatura Comunicaciones Inalámbricas y Protocolos para el Internet de las Cosas.


Fig. 7: Esquema de conexiones del nodo autónomo (Cirkit Designer)

## 3. Estación base

Usaré mi vieja y fiable Raspberry Pi 1 Model B Rev1.0 que empleé para una de las prácticas de la asignatura Comunicaciones Inalámbricas y Protocolos para el Internet de las Cosas. Esta versión tiene las siguientes características relevantes:

Procesador: Broadcom BCM2835 con núcleo único ARM1176JZF-S a 700 MHz.
Memoria: 256 MB SDRAM (compartida entre CPU y GPU).
Red: puerto Ethernet RJ45 10/100 Mbps. Conectado a mi red local.
USB: 2 puertos USB 2.0. Puentee los fusibles poliméricos integrados para no limitar la corriente con la que se alimentan los dispositivos USB.
Almacenamiento: tarjeta MicroSD de 64GB.
GPIO: cabecera de 26 pines (8 pines GPIO, más pines para I2C, SPI y UART). Los pines I2S no están completos como veremos más adelante.
Alimentación: entrada Micro USB, uso una fuente de 5V 3A.


Fig. 8: Mi Raspberry Pi 1 Model B Rev1.0

## 3.1. Periféricos

Pantalla: la empleo para mostrar los datos recibidos del nodo, incluyendo alertas y controlar los relés conectados a la estación base. Uso un módulo con una pantalla de 2 pulgadas con una controladora ST7789 y 320x240 px de resolución con codificador rotatorio EC11 y un botón extra integrados (en la práctica 4 botones). La pantalla se conecta por SPI usando la librería luma.lcd

[17] y se dibuja usando
Pillow

[18]
. La pantalla funciona a 3,3 V sacados de la cabecera de la Raspberry Pi. LED de estado: empleado para indicar el estado del sistema. Uso un WS2812B conectado directamente. Tuve un conflicto con la salida analógica de audio al usar el pin GPIO18 que me costó depurar: el LED no funcionaba en mi programa pero sí en los que lo probaba solo, y el audio al tratar de hacer funcionar los dos a la vez sonaba mal. Eso se debía a que ambos usan PWM y se pisaban; cambiando el LED al pin GPIO21 , que funciona usando PCM y es compatible con la librería usada

[19]
,
lo solucioné. El LED lo alimento a 5V, aunque la lógica de la Raspberry Pi funciona a 3,3 V, no parece que dé problemas.
Amplificador y altavoz: usados para emitir alertas y avisos. Al principio pensé en usar un amplificador digital, concretamente un módulo con un MAX98357, conectado por I2S a los GPIO para obtener la mejor calidad de sonido. No obstante, al ir a conectarlo me di cuenta de que esta versión de la Raspberry Pi, con 26 pines en la cabecera y anterior a la revisión con la cabecera extra, no expone todos los pines necesarios para usar I2S, con lo que finalmente empleo un amplificador analógico, un módulo con un PAM8302A, conectado al jack de 3,5 mm y a un pequeño altavoz de 8 Ω y 0,5 W, con lo que me es suficiente con alimentarlo a 3,3 V.
Relés: uso también un módulo con 8 relés a 5V para simular la apertura de válvulas de riego y la activación de otros sistemas. La lógica de control de los relés la tengo funcionando a 3,3 V mientras que las bobinas están alimentadas a 5V, valor para el que están diseñadas. Solo conecto 4 de los relés, más que suficientes para realizar pruebas, y uso sus LEDs de estado para comprobar que funcionan correctamente.


Fig. 9: La estación base ya montada. La Raspberry Pi está en la parte posterior

## 3.2. Alimentación

La estación base, y todos sus periféricos, se alimentan a través de una fuente de 5V 3A conectada a la toma de alimentación de la Raspberry Pi. Tengo que arrancar la estación base con el nodo autónomo conectado porque si lo conecto después la Raspberry Pi se bloquea por el pico de potencia requerido, no es un gran inconveniente.


Fig. 10: Esquema de conexiones de la estación base (Cirkit Designer)

## 3.3. Configuración inicial

Uso DietPi

[20] como imagen para la Raspberry Pi dado que es una imagen mínima y tiene mejor rendimiento (el sistema en funcionamiento consume menos de 55 MB de RAM) que una imagen de Raspbian completa.

Activo el audio instalando ALSA y configurando la tarjeta de sonido para que use la interna de la Raspberry Pi, también activo SPI. Todo se hace desde la consola usando dietpi-config , la herramienta de configuración de DietPi. Instalo también las dependencias de Python para que funcionen los GPIO.


Fig. 11: Software disponible en DietPi para interacción con hardware

También son necesarios los paquetes adicionales | libjpeg-dev libtiff6 libopenjp2-7 libxcb1
libfreetype6 | para que funcione la pantalla y el paquete espeak-ng para los avisos hablados.

## 3.4. Programa de monitorización y control

El programa de la estación base, escrito en Python y organizado como paquete instalable, recibe del nodo por el puerto USB el JSON con los datos de los sensores y muestra por la pantalla los valores obtenidos del nodo autónomo y permite la activación de los relés durante una duración de tiempo variable. Uso GitHub

[21] para sincronizar mi repositorio local, después de clonarlo e instalar las dependencias del sistema podemos instalar el programa usando:

# desde estacion-base/

python3 -m venv ~/venvs/estacion
source ~/venvs/estacion/bin/activate
pip install --upgrade pip
pip install -e .
cp .env.example .env # rellenar los tokens
sudo ~/venvs/estacion/bin/python -m estacion_base

Como se ve necesitamos usar sudo para ejecutar el programa debido al uso de DMA por la librería neopixel que controla el WS2812B; no es lo mejor pero las alternativas que he visto no me convencían, al menos nos quitamos de añadir nuestro usuario a los grupos gpio , spi , audio y dialout para tener permisos para usar el resto de periféricos.

Uso un fichero de configuración config.py con todas las constantes y los tokens de acceso a Ubidots en un fichero .env fuera del repositorio. He usado hilos independientes para varias tareas (lectura del nodo, entrada, comunicación con Ubidots, reproducción de audio y dibujo de la pantalla) para evitar bloqueos que surgieron durante el desarrollo y dar mayor fluidez al programa.

El programa se controla usando el botón del encoder en pulsación corta para abrir el menú de selección de relés que se pueden cambiar moviendo el encoder y activar usando el propio botón integrado. El botón externo KEY0 se usa para volver de los menús y apagar la alerta que se emite cuando se detecta un rayo, mientras que una pulsación prolongada de este botón permite además apagar todos los relés y volver a la pantalla principal.

El LED WS2812B indica el estado del sistema siguiendo esta tabla de colores:

Verde: funcionamiento normal.
Amarillo: tierra seca.
Violeta: interferencia detectada por el sensor de rayos.
Azul: riego en proceso.
Rojo: rayo detectado.
Para las alertas y avisos al principio usé un tono de 880 Hz generado usando speaker-test -t sine -f 880 -c 1 -l 1 , pero como quería también aprovechar el sonido para más cosas, al final he acabado usando espeak-ng
[22] a través de py-espeak-ng
[23] para hacer text-to-speech y emitir también avisos cuando se activan y desactivan los relés. El tono se ha dejado como respaldo si no funciona la voz. Me ha sorprendido lo bien que funciona este programa en una SBC tan limitada como mi Raspberry Pi.

Las automatizaciones de prueba residen en la estación base para ser independientes de internet y tener menor latencia. Ahora hay una muy básica que enciende el relé 1 durante 10 segundos cuando la humedad baja de un nivel preprogramado y no se puede repetir hasta 10 minutos después y otra que activa una alerta cuando detectamos un rayo a menos de 15 km.

Almaceno también de forma local, en la carpeta data , un fichero de log por cada arranque del programa con los datos del nodo que vamos recibiendo y el estado de los relés de la estación base.

El siguiente diagrama muestra la arquitectura del programa y el flujo de datos:


Fig. 12: Arquitectura del programa y flujo de datos

## 4. Plataforma IoT en la nube: Ubidots

Elijo Ubidots STEM[24] por su sencillez y porque creo que su cuenta gratuita cubre mis requisitos pese a estar limitada. El panel de control que uso muestra todos los datos del nodo además del estado de los relés y permite su accionamiento remoto.


Fig. 13: Panel de control de Ubidots

Envío los datos desde la estación base usando su API por HTTP POST

[25] cada 30 segundos. Leo también el estado de los relés desde Ubidots para poder activarlos a distancia.

Separo los datos que envío en dos dispositivos: nodo-1 con los sensores y estacion-base con los relés.

nodo-1 :

{"temp_amb":25.30,"hum_amb":42.0,"presion_hpa":905.2,"luz_lux":384.5, "uv_index":1,"temp_suelo":22.8,"hum_suelo":4095,"hum_suelo_pct":0, "v_bat":0,"i_ma":0,"p_mw":0,"estado_rayos":0,"dist_km":0}

uv_index : índice UV ya convertido, de 0 a 10.
hum_suelo_pct : humedad ya convertida, de 0 a 100%.
estado_rayos : numérico 0 ok, 1 disturber, 2 rayo, 3 ruido. Tuve que convertirlo porque Ubidots al parecer solo acepta números, de todas formas es mejor, ahorramos datos.

estacion-base :

{"rele_1":1,"rele_2":0,"rele_3":0,"rele_4":0}

rele_N : 0/1 con el estado real de cada relé. Señalar que se envía 0 para apagado y 1 para encendido, al contrario de como funcionan realmente (activos en LOW).
Tuve algún problema de rebote con los relés al compartir en Ubidots su estado y su accionamiento, y de hecho su funcionamiento sigue sin ser perfecto, pero era más una prueba de concepto que otra cosa puesto que la intención es controlar los relés directamente desde la estación base, ya sea usando automatizaciones o su control manual integrado. Se han implementado mecanismos de control de errores (404, 429) en la transmisión también con el fin de evitar el uso excesivo de la API proporcionada.

## 5. Conclusiones y mejoras futuras

Esta práctica me ha servido para poner en práctica los conocimientos adquiridos durante el curso y sortear limitaciones de hardware, también para tratar de realizar un código más limpio y tener en cuenta aspectos como la limpieza de los pines GPIO y dispositivos al salir que a veces no tenemos en cuenta. Tampoco me ha supuesto un desafío excesivo, si no contamos con el tiempo invertido en cosas prescindibles como mejorar la interfaz gráfica de la pantalla empleada o el uso de los relés a distancia desde Ubidots, dado que me dedico a la programación de sistemas embebidos (fundamentalmente STM32 en C puro). Considero útil también el descubrimiento de Ubidots y su facilidad de uso a la hora de visualizar datos.

Hay muchas mejoras que se pueden implementar en el sistema, algunas de ellas se llevarán a cabo en la práctica final de la asignatura Comunicaciones Inalámbricas y Protocolos para el Internet de las Cosas. Entre ellas destaco:

Uso de otro protocolo de comunicaciones que sea inalámbrico, el nodo autónomo debe estar separado de la estación base.
Uso de una batería y panel solar en el nodo autónomo para alimentarlo.
Emplear MQTT para las comunicaciones entre nodo autónomo y estación base y con Ubidots. Hacer el sistema realmente escalable para que una sola estación base pueda soportar múltiples nodos autónomos que se conectarían fácilmente sin tocar el código.
Realizar cajas impresas en 3D diseñadas a medida tanto para el nodo autónomo, separando los sensores que necesitan estar en el exterior con sus propias carcasas, como para la estación base. Usar mosfets, como el Si2312, para apagar los sensores cuando no se utilizan en el nodo autónomo y así ahorrar energía.
Añadir al nodo autónomo un sensor de pluviometría para registrar el nivel de lluvia y un anemómetro y veleta para registrar la velocidad y dirección del viento.
Usar un ESP32-C6 reemplazando al ESP32-C3 empleado por ser la última versión de esta gama y tener mejor conectividad, aunque en principio nosotros no emplearemos ni WiFi ni Bluetooth para comunicarnos.
Firmware del nodo autónomo actualizable vía OTA, uso de secure boot.
Usar mejores sensores de suelo ya que los empleados se corroen fácilmente como he comprobado.

Crear PCBs para todo el sistema, especialmente para el nodo autónomo, y así reducir su tamaño y coste.

1. Viveros Integrales El Ejidillo Disponible en: https://ejidillo.com/. Accedido el 12/8/2026. ↩︎
2. Hydro Environment - Guía Práctica: La Importancia de la Luz en el Cultivo. Disponible en: https://hydroenv.com.mx/guia-practica-la-importancia-de-la-luz-en-el-cultivo/. Accedido el 2/9/2026. ↩︎
3. UPRtek - El Espectro UVA en la Agricultura de Interior: Mejora de la calidad y el rendimiento de los cultivos con iluminación UV-A. Disponible en: https://www.uprtek.com/es/blogs/indoor-agriculture-leveraging-the-power-of-uva-spectrum. (https://www.uprtek.com/es/blogs/indoor-agriculture-leveraging-the-power-of-uva-spectrum) Accedido el 2/9/2026. ↩︎
4. EOS Data Analytics - Temperatura Del Suelo Para La Siembra Y El Cultivo. Disponible en: https://eos.com/es/blog/temperatura-del-suelo/. Accedido el 2/9/2026. ↩︎
5. TENSTAR ROBOT - Placa de desarrollo TENSTAR ROBOT ESP32 C3 SuperMini Disponible en: https://tenstar.pro/robot-esp32-c3-supermini/. Accedido el 24/8/2026. ↩︎
6. GitHub - Adafruit AHTX0 (AHT10 & AHT20). Disponible en: https://github.com/adafruit/Adafruit_AHTX0. Accedido el 27/8/2026. ↩︎
7. GitHub - Adafruit BMP280 Driver (Barometric Pressure Sensor). Disponible en: https://github.com/adafruit/adafruit_bmp280_library. Accedido el 27/8/2026. ↩︎
8. GitHub - Adafruit_VEML7700. Disponible en: https://github.com/adafruit/Adafruit_VEML7700. Accedido el 27/8/2026. ↩︎
9. Garry's blog - Ben Franklin and DIY Lightning Detection using a AS3935 Lightning Sensor. Disponible en: https://garrysblog.com/2025/07/23/ben-franklin-and-diy-lightning-detection-using-a-as3935-lightning-sensor/. (https://garrysblog.com/2025/07/23/ben-franklin-and-diy-lightning-detection-using-a-as3935-lightning-sensor/) Accedido el 27/8/2026. ↩︎
10. GitHub - SparkFun AS3935 Lightning Detector Arduino Library. Disponible en: https://github.com/sparkfun/SparkFun_AS3935_Lightning_Detector_Arduino_Library. Accedido el 27/8/2026. ↩︎
11. Tasmota - AS3935 Franklin Lightning sensor. Disponible en: https://tasmota.github.io/docs/AS3935/#cjmcu-board. Accedido el 27/8/2026. ↩︎
12. DitecnoMakers - Medir la humedad de la tierra con Arduino y un Higrómetro FC-28. Disponible en: https://tasmota.github.io/docs/AS3935/#cjmcu-board. Accedido el 27/8/2026. ↩︎
13. PJRC - OneWire Arduino Library, connecting 1-wire devices (DS18S20, etc) to Teensy. Disponible en: https://tasmota.github.io/docs/AS3935/#cjmcu-board. Accedido el 27/8/2026. ↩︎
14. GitHub - Arduino Temperature Control Library. Disponible en: https://github.com/milesburton/Arduino-Temperature-Control-Library. (https://github.com/milesburton/Arduino-Temperature-Control-Library) Accedido el 27/8/2026. ↩︎
15. GitHub - ArduinoJson. Disponible en: https://github.com/bblanchon/ArduinoJson. Accedido el 27/8/2026. ↩︎
16. GitHub - Arduino library for the INA226 power sensor. Disponible en: https://github.com/RobTillaart/INA226. Accedido el 27/8/2026. ↩︎
17. PyPi - luma.lcd. Disponible en: https://pypi.org/project/luma.lcd/. Accedido el 2/9/2026. ↩︎
18. Pillow - Documentation. Disponible en: https://pillow.readthedocs.io/en/stable/. Accedido el 2/9/2026.

↩︎
19. Adafruit - Adafruit NeoPixel Überguide. Disponible en: https://learn.adafruit.com/adafruit-neopixel-uberguide/python-circuitpython. (https://learn.adafruit.com/adafruit-neopixel-uberguide/python-circuitpython) Accedido el 2/9/2026. ↩︎
20. DietPi - Lightweight justice for your SBC!. Disponible en: https://ejidillo.com/quienes-somos/. Accedido el 3/9/2026. ↩︎
21. GitHub - Estación Agrícola Autónoma. Disponible en: https://github.com/alexprovencio/estacion-agricola. (https://github.com/alexprovencio/estacion-agricola) Accedido el 2/9/2026. ↩︎
22. GitHub - eSpeak NG Text-to-Speech. Disponible en: https://github.com/espeak-ng/espeak-ng. Accedido el 2/9/2026. ↩︎

23. GitHub - py-espeak-ng. Disponible en: https://github.com/gooofy/py-espeak-ng. Accedido el 2/9/2026.

↩︎
24. Ubidots - STEM. Disponible en: https://ubidots.com/stem. Accedido el 2/9/2026. ↩︎
25. Docs Ubidots - HTTP Overview. Disponible en: https://docs.ubidots.com/v1.6/reference/http. Accedido el 2/9/2026. ↩︎

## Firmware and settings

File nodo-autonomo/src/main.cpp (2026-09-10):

/**
 * @file
 * @brief Estación Agrícola - Nodo solar autónomo
 * @author Alejandro Provencio Sanz <aprovenci9@alumno.uned.es>
 * @date 2026-09-03
 *
 * Práctica final de Comunicaciones Inalámbricas y Protocolos para el IoT.
 *
 * Lee todos los sensores del nodo y envía las lecturas por el USB
 * en formato JSON para que la estación base las procese.
 *
 * @details
 * Mapa de conexiones (ESP32-C3 Supermini y módulos):
 * @code
 *   Todos los módulos van alimentados a 3V3 y con GND común para todo.
 *   I2C SDA          <- GPIO0  AHT20+BMP280, VEML7700, INA226 y AS3935
 *   I2C SCL          <- GPIO1  AHT20+BMP280, VEML7700, INA226 y AS3935
 *   AS3935 IRQ       <- GPIO5  Interrupción de detección de rayos
 *   GUVA-S12SD ADC   <- GPIO3  Índice UV, entrada analógica
 *   Higrómetro ADC   <- GPIO4  Humedad de suelo, entrada analógica
 *   DS18B20 Data     <- GPIO6  Temperatura de suelo, OneWire, pull-up de 4,7 kΩ
 *   INA226 IN+       <- CN3791 BAT+
 *   INA226 IN-       <- MH-CD41 BAT+
 *   INA226 VBS       <- CN3791 BAT+
 *   MH-CD41 BAT+     <- CN3791 BAT-
 *   MH-CD41 BAT-     <- GND
 *   MH-CD41 OUT+     <- ESP32-C3 5V
 *   MH-CD41 OUT-     <- GND
 *   CN3791 BAT+      <- +Batería de 3,7V y MH-CD41 BAT+
 *   CN3791 BAT-      <- -Batería de 3,7V y GND
 *   CN3791 SOLAR IN+ <- + Panel Solar hasta 6V
 *   CN3791 SOLAR IN- <- - Panel Solar hasta 6V
 *   Para el AS3935 además:
 *      SI a 3V3
*       MISO a GND
*       CS a GND
 * @endcode
 */

#include <Arduino.h>
#include <Wire.h>
#include <ArduinoJson.h>

#include <Adafruit_AHTX0.h>
#include <Adafruit_BMP280.h>
#include <Adafruit_VEML7700.h>
#include <INA226.h>
#include <OneWire.h>
#include <DallasTemperature.h>
#include <SparkFun_AS3935.h>
#include <WiFi.h>
#include "esp_mac.h"

#if defined(TRANSPORTE_WIFI)
#include <AsyncMqttClient.h>
#include <Ticker.h>
#include "wifi_manager.h"
#endif
#if defined(TRANSPORTE_ESP_NOW)
#include <esp_now.h>
#include <esp_wifi.h>
#endif
#include "secrets.h"

// Pines
#define PIN_I2C_SDA        0
#define PIN_I2C_SCL        1
#define PIN_AS3935_IRQ     5
#define PIN_ADC_GUVA       3
#define PIN_ADC_HIGROMETRO 4
#define PIN_DS18B20        6
// LED integrado (GPIO8)
#define PIN_LED             8

// UART al Faketec con Meshtastic
// GPIO21 = TX (al RX del Faketec), GPIO20 = RX (al TX del Faketec)
// No son D3 y D4 marcados en la placa!!!!
#define SERIAL1_RX         20
#define SERIAL1_TX         21
#define MESHTASTIC_BAUD    38400

#define UART_BAUD          115200
// Tiempo entre lecturas de los sensores y envío de los datos
#define INTERVALO_MS       29920 // 30s para Meshtastic

// Dirección I2C de los módulos
#define AS3935_ADDR        0x03 // A0 y A1 a VCC
#define INA226_ADDR        0x40 // A0 y A1 a GND
#define BMP280_ADDR        0x77
// Dirección de backup del BMP280
#define BMP280_B_ADDR      0x76

// Códigos de evento que devuelve el AS3935 al leer la interrupción
#define RAYO_INT           0x08
#define DISTURBER_INT      0x04
#define RUIDO_INT          0x01

// INA226: ajusta al valor real del shunt del módulo y la corriente 
// máxima que puede medir sin saturarse (sacado de aliexpress).
#define INA_SHUNT_OHM     0.1
#define INA_MAX_CURRENT_A 0.8

Adafruit_AHTX0 aht;
Adafruit_BMP280 bmp;
Adafruit_VEML7700 veml;
INA226 ina(INA226_ADDR);
SparkFun_AS3935 rayos(AS3935_ADDR);
OneWire oneWire(PIN_DS18B20);
DallasTemperature ds18b20(&oneWire);

// Interrupción del sensor de rayos
volatile bool as3935_interrupt = false;
// Estado latcheado por la tarea (prioridad): 0=ok, 1=ruido, 2=disturber, 3=rayo
volatile uint8_t rayo_evento = 0;
volatile uint8_t rayo_dist_km = 0;

void IRAM_ATTR onAs3935() {
  as3935_interrupt = true;
}

// Código de prioridad de un evento del AS3935 (rayo > disturber > ruido).
uint8_t _codigoEvento(int ev) {
  switch (ev) {
    case RAYO_INT:    return 3;
    case DISTURBER_INT: return 2;
    case RUIDO_INT:   return 1;
    default:          return 1;
  }
}

// Tarea: atiende la interrupción y latchea el evento por prioridad, para no
// perder un rayo si después llega un disturber/ruido antes del siguiente envío.
// Lee por I2C el registro.
void tareaRayos(void*) {
  for (;;) {
    if (as3935_interrupt) {
      as3935_interrupt = false;
      int ev = rayos.readInterruptReg();
      uint8_t cod = _codigoEvento(ev);
      if (cod >= rayo_evento) {  // no pisar un rayo con algo menor
        rayo_evento = cod;
        if (ev == RAYO_INT) rayo_dist_km = rayos.distanceToStorm();
      }
    }
    vTaskDelay(100 / portTICK_PERIOD_MS); // 100 ms, PROBAR 
  }
}

// Imprime la MAC real del dispositivo (leída de efuse, no depende del estado WiFi).
void printMac(const char* label) {
  uint8_t mac[6];
  esp_read_mac(mac, ESP_MAC_WIFI_STA);
  Serial.printf("%s: %02X:%02X:%02X:%02X:%02X:%02X\n",
                label, mac[0], mac[1], mac[2], mac[3], mac[4], mac[5]);
}

#if defined(TRANSPORTE_WIFI)
WiFiManager wifiManager;
AsyncMqttClient mqttClient;
Ticker mqttReconnectTimer;
// Último intento de conexión MQTT desde loop() (reintento periódico)
unsigned long lastMqttAttempt = 0;
#endif
// Contador incremental para medir pérdida de paquetes
uint32_t seq = 0;

// Sensores ambientales: temperatura, humedad, presión, luz y UV (analógico)
void leerAmbientales(JsonObject d) {
  sensors_event_t hum, temp;
  if (aht.getEvent(&hum, &temp)) {
    d["ta"] = temp.temperature;
    d["ha"] = hum.relative_humidity;
  }
  if (bmp.takeForcedMeasurement()) {
    d["pa"] = bmp.readPressure() / 100.0;
  }
  d["lx"] = veml.readLux();
  d["uv"] = analogRead(PIN_ADC_GUVA);  // índice UV, valor ADC crudo
}

// Sensores de suelo: temperatura y humedad (analógico)
void leerSuelo(JsonObject d) {
  ds18b20.requestTemperatures();
  d["ts"] = ds18b20.getTempCByIndex(0);
  d["hs"] = analogRead(PIN_ADC_HIGROMETRO);
}

// Módulo de energía INA226: tensión, corriente y potencia de la batería
void leerEnergia(JsonObject d) {
  d["vb"] = ina.getBusVoltage();
  d["ia"] = ina.getCurrent_mA();
  d["pw"] = ina.getPower_mW();
}

// Detector de rayos AS3935: usa el estado latcheado por tareaRayos (por prioridad).
// Se manda como int (0=ok, 1=ruido, 2=disturber, 3=rayo). Tras reportar se resetea.
void leerRayos(JsonObject d) {
  uint8_t ev = rayo_evento;
  d["re"] = ev;                          // int
  if (ev == 3) d["rd"] = rayo_dist_km;   // distancia solo si hay rayo
  rayo_evento = 0;
  rayo_dist_km = 0;
}

#if defined(TRANSPORTE_WIFI)
void connectToMqtt() {
  Serial.println("Conectando a MQTT...");
  mqttClient.connect();
}

void WiFiEvent(WiFiEvent_t event) {
  Serial.printf("[WiFi-event] %d\n", event);
  switch(event) {
    case ARDUINO_EVENT_WIFI_AP_START:
      Serial.print("AP iniciado IP: ");
      Serial.println(WiFi.softAPIP());
      break;
    case ARDUINO_EVENT_WIFI_AP_STACONNECTED:
      Serial.println("Cliente conectado al AP");
      connectToMqtt();
      break;
    case ARDUINO_EVENT_WIFI_AP_STADISCONNECTED:
      Serial.println("Cliente desconectado del AP");
      break;
    case ARDUINO_EVENT_WIFI_AP_STAIPASSIGNED:
      Serial.println("IP asignada a cliente, conectando MQTT...");
      connectToMqtt();
      break;
    default: break;
  }
}

void onMqttConnect(bool sessionPresent) {
  Serial.println("MQTT conectado");
  mqttClient.publish(MQTT_TOPIC_ESTADO, 1, true, "{\"estado\":\"online\"}");
}

void onMqttDisconnect(AsyncMqttClientDisconnectReason reason) {
  Serial.printf("MQTT desconectado %d\n", (int)reason);
  if (WiFi.softAPgetStationNum() > 0 || WiFi.isConnected()) {
    mqttReconnectTimer.once(2, connectToMqtt);
  }
}
#elif defined(TRANSPORTE_ESP_NOW)
esp_now_peer_info_t peerInfo = {};

void iniciarEspNow() {
  WiFi.mode(WIFI_STA);
  if (esp_now_init() != ESP_OK) {
    Serial.println("Error: no se pudo iniciar ESP-NOW");
    return;
  }
  // Nodo y puente deben estar en el mismo canal.
  esp_wifi_set_channel(ESP_NOW_CHANNEL, WIFI_SECOND_CHAN_NONE);
  memcpy(peerInfo.peer_addr, BRIDGE_MAC, 6);
  peerInfo.channel = ESP_NOW_CHANNEL;
  peerInfo.ifidx = WIFI_IF_STA;
  peerInfo.encrypt = false;
  if (esp_now_add_peer(&peerInfo) != ESP_OK) {
    Serial.println("Error: añadiendo peer (puente)");
  }
}
#endif

void setup() {
  // Consola de depuración por USB (Serial)
  Serial.begin(UART_BAUD);
  delay(500);

  // MAC del nodo: cópiala a secrets.h del puente (NODE_MAC)
  printMac("MAC del nodo");

#if defined(TRANSPORTE_WIFI)
  WiFi.onEvent(WiFiEvent);
  Serial.println("Iniciando WiFi...");
  wifiManager.begin();

  mqttClient.onConnect(onMqttConnect);
  mqttClient.onDisconnect(onMqttDisconnect);
  mqttClient.setServer(MQTT_HOST, MQTT_PORT);
  mqttClient.setCredentials(MQTT_USER, MQTT_PASS);
  mqttClient.setClientId(MQTT_CLIENT_ID);
  mqttClient.setWill(MQTT_TOPIC_ESTADO, 1, true, "{\"estado\":\"offline\"}");
#elif defined(TRANSPORTE_ESP_NOW)
  iniciarEspNow();
#elif defined(TRANSPORTE_MESHTASTIC)
  Serial1.begin(MESHTASTIC_BAUD, SERIAL_8N1, SERIAL1_RX, SERIAL1_TX);
#endif

  Wire.begin(PIN_I2C_SDA, PIN_I2C_SCL);
  pinMode(PIN_AS3935_IRQ, INPUT);
  pinMode(PIN_LED, OUTPUT);
  digitalWrite(PIN_LED, HIGH);
  attachInterrupt(digitalPinToInterrupt(PIN_AS3935_IRQ), onAs3935, RISING);

  aht.begin();
  // El BMP280 puede tener dos direcciones
  if (!bmp.begin(BMP280_ADDR)) bmp.begin(BMP280_B_ADDR);
  bmp.setSampling(Adafruit_BMP280::MODE_FORCED);
  veml.begin();
  ina.begin();
  // Calibración del INA226 NECESARIA
  ina.setMaxCurrentShunt(INA_MAX_CURRENT_A, INA_SHUNT_OHM);
  ds18b20.begin();

  if (rayos.begin()) {
    rayos.setIndoorOutdoor(OUTDOOR);
    // Ajustar esto para usarlo realmente
    //rayos.setNoiseLevel(2-4)
    //rayos.watchdogThreshold(2)
    //rayos.spikeRejection(2-3)
    delay(50);

  } else {
    Serial.println("Error: AS3935 no responde");
  }

  // Tarea que latchea los eventos de rayo por prioridad para que no se pierdan.
  xTaskCreate(tareaRayos, "rayos", 4096, NULL, 1, NULL);

  Serial.println("Nodo listo, enviando lecturas");
}

void loop() {
#if defined(TRANSPORTE_WIFI)
  wifiManager.loop();

  // Si hay clientes en el AP y MQTT sigue caído reintenta cada 5 s
  if (!mqttClient.connected() && WiFi.softAPgetStationNum() > 0 &&
      millis() - lastMqttAttempt > 5000) {
    lastMqttAttempt = millis();
    connectToMqtt();
  }
#endif

  JsonDocument doc;
  doc["nid"] = NODE_ID;
  doc["seq"] = seq++;
  doc["t"] = millis() / 1000;
  leerAmbientales(doc.as<JsonObject>());
  leerSuelo(doc.as<JsonObject>());
  leerEnergia(doc.as<JsonObject>());
  leerRayos(doc.as<JsonObject>());

  // Reducir la precisión de los flotantes a 1 decimal: cabe en un paquete LoRa.
  doc["ta"] = roundf((float)doc["ta"] * 10) / 10;
  doc["ha"] = roundf((float)doc["ha"] * 10) / 10;
  doc["pa"] = roundf((float)doc["pa"] * 10) / 10;
  doc["lx"] = roundf((float)doc["lx"] * 10) / 10;
  doc["ts"] = roundf((float)doc["ts"] * 10) / 10;
  // La batería necesita 2 decimales.
  doc["vb"] = roundf((float)doc["vb"] * 100) / 100;
  doc["ia"] = roundf((float)doc["ia"] * 10) / 10;
  doc["pw"] = roundf((float)doc["pw"] * 10) / 10;


#if defined(TRANSPORTE_WIFI)
  // Depuración por USB + MQTT a la estación base
  serializeJson(doc, Serial);
  Serial.println();
  char buffer[600];
  serializeJson(doc, buffer, sizeof(buffer));
  if (mqttClient.connected()) {
    mqttClient.publish(MQTT_TOPIC_TELEMETRIA, 1, false, buffer);
  }
#elif defined(TRANSPORTE_USB)
  // Enlace directo a la base: wrapper {"enlace":{"origen":"usb"},"dato":...}
  char inner[600];
  size_t n = serializeJson(doc, inner, sizeof(inner));
  Serial.printf("{\"enlace\":{\"origen\":\"usb\"},\"dato\":");
  Serial.write(inner, n);
  Serial.println("}");
#elif defined(TRANSPORTE_ESP_NOW)
  // Envío por ESP-NOW al puente (el puente añade el enlace y el RSSI)
  char buffer[600];
  size_t n = serializeJson(doc, buffer, sizeof(buffer));
  esp_now_send(BRIDGE_MAC, (const uint8_t*)buffer, n);
  // Depuración por USB
  serializeJson(doc, Serial);
  Serial.println();
#elif defined(TRANSPORTE_MESHTASTIC)
  // El JSON ya cabe en un paquete LoRa .
  serializeJson(doc, Serial1);
  Serial1.println();
  // Depuración por USB
  serializeJson(doc, Serial);
  Serial.println();
  // Depuración por USB de lo que se recibe del Faketec (malla LoRa)
  if (Serial1.available()) Serial.write(Serial1.read());
#endif

  // Parpadeo del LED integrado para indicar envío
  digitalWrite(PIN_LED, LOW);
  delay(80);
  digitalWrite(PIN_LED, HIGH);

  delay(INTERVALO_MS);
}

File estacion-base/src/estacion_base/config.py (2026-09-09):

#!/usr/bin/env python3
# -*- coding: utf-8 -*-
"""Estación Agrícola - Estación base - Configuración.

Pines, umbrales y configuración.

Autor: Alejandro Provencio Sanz <aprovenci9@alumno.uned.es>
Fecha: 2026-08-31

Práctica final de Sistemas Digitales para el Internet de las Cosas.

Mapa de conexiones (Raspberry Pi 1 BCM 26 pines):

  ST7789: VDD->3V3, SCL=11, SDA=10, RES=24, DC=25, CS=8, BLK->3V3.
  EC11 y botón KEY0: TRA=17, TRB=4, PSH=22, K0=23.
  Relés (4): VCC->3V3, IN1=0, IN2=1, IN7=7, IN8=9, JD-VCC->5V.
  WS2812B: +5V->5V, Din=21.
  PAM8302A: Vin->3V3, A+ al tip del jack de 3,5mm, A- a su cubierta.
      La salida del amplificador se conecta a un altavoz de 8Ω y 0,5W.
      El jack de 3,5mm se conecta a la salida de audio de la RPi.
"""

import os
from dotenv import load_dotenv

# Carga .env con los secretos desde la raíz del proyecto estacion-base
# y desde el directorio actual por si se ejecuta desde otro sitio
env_path = os.path.join(os.path.dirname(__file__), "..", "..", ".env")
load_dotenv(dotenv_path=env_path)
load_dotenv()  # fallback

# Pantalla SPI
PIN_DC = 25
PIN_RES = 24

# Relés (activo LOW)
PIN_RELES = [0, 1, 7, 9]

# Encoder EC11 y botón K0
PIN_EC_TRA = 17
PIN_EC_TRB = 4
PIN_EC_PSH = 22
PIN_K0 = 23

# LED WS2812B Usando PCM
PIN_LED_WS = 21
LED_COLORS = {
    "ok":        (0, 255, 0),    # Verde
    "seco":      (255, 255, 0),  # Amarillo
    "disturber": (255, 0, 255),  # Violeta
    "riego":     (0, 150, 255),  # Azul
    "rayo":      (255, 0, 0),    # Rojo
}
LED_PRIORIDAD = ["rayo", "disturber", "riego", "seco", "ok"]

# Enlace con el Nodo Autónomo: puerto serie e inyector (USB/ESP-NOW/Meshtastic)
BAUD = int(os.getenv("BAUD", "38400"))  # Default Meshtastic

# Enlace de entrada del nodo: "mqtt" (WiFi-MQTT) o "serial" (USB/ESP-NOW/Meshtastic).
ENLACE_NODO = os.getenv("ENLACE_NODO", "serial")
# Puerto del inyector serie (USB del nodo, del puente ESP-NOW o del 
# Faketec Meshtastic).
PUERTO_SERIAL = os.getenv("PUERTO_SERIAL", "/dev/ttyAMA0")

# Identificador de este nodo.
NODO_ID = os.getenv("NODO_ID", "nodo-1")

# Broker MQTT Mosquitto local
MQTT_HOST = os.getenv("MQTT_HOST", "127.0.0.1")
MQTT_PORT = int(os.getenv("MQTT_PORT", "8883"))
MQTT_USER = os.getenv("MQTT_USER", "estacion-base")
MQTT_PASS = os.getenv("MQTT_PASS", "")
# TLS con el broker local. MQTT_CA -> CA de los certificados del broker.
MQTT_TLS = os.getenv("MQTT_TLS", "true").lower() in ("1", "true", "yes")
MQTT_CA = os.getenv("MQTT_CA",
                    os.path.abspath(os.path.join(os.path.dirname(__file__), "..", "..", "ca.crt")))

# Ubidots
# Cada dispositivo tiene su propio token y label. Se leen del .env 
# para no subir secretos a git.
UBI_TOKEN_ESTACION = os.getenv("UBI_TOKEN_ESTACION", "")
UBI_DEVICE_ESTACION = os.getenv("UBI_DEVICE_ESTACION", "estacion-base")
UBI_TOKEN_NODO = os.getenv("UBI_TOKEN_NODO", "")
UBI_DEVICE_NODO = os.getenv("UBI_DEVICE_NODO", "nodo-1")
# Fijamos el tiempo de actualización en la nube para no saturarla.
INTERVALO_CLOUD = int(os.getenv("INTERVALO_CLOUD", "30"))

# Mapa para convertir estados de rayos a código numérico para Ubidots.
UBI_ESTADO_RAYOS = {"ok": 0, "disturber": 1, "rayo": 2, "ruido": 3}

# Calibración higrómetro
# 4095 = seco al aire, 1800 = saturado.
# Ajustar tras probar en tierra real!
HUM_ADC_SECO = int(os.getenv("HUM_ADC_SECO", "4095"))
HUM_ADC_SATURADO = int(os.getenv("HUM_ADC_SATURADO", "1800"))

# Índice UV dado por el GUVA-S12SD
# 0.1 V por índice (1 V = índice 10).
UV_MV_POR_INDICE = int(os.getenv("UV_MV_POR_INDICE", "100"))
UV_INDICE_MAX = int(os.getenv("UV_INDICE_MAX", "10"))

# Automatismos de prueba
HUM_SECO = int(os.getenv("HUM_SECO", "3800"))
HUM_HUMEDO = int(os.getenv("HUM_HUMEDO", "3000"))
# Distancia mínima en km del rayo detectado para emitir la alerta
DIST_ALERTA = int(os.getenv("DIST_ALERTA", "15"))
# Tiempo de riego cuando la tierra está seca en segundos
TIEMPO_RIEGO = int(os.getenv("TIEMPO_RIEGO", "10"))
# Tiempo mínimo entre riegos cuando la tierra está seca
TIEMPO_ENTRE_RIEGOS = int(os.getenv("TIEMPO_ENTRE_RIEGOS", "600"))
RELE_RIEGO = 0      # índice del relé usado para la bomba de riego
RELE_ALERTA = 1     # índice del relé usado para la alerta de tormenta

# Duraciones configurables para la activación manual de los relés
DURACIONES = [5, 10, 30]

# Tipografía
FONT_BIG = "/usr/share/fonts/truetype/dejavu/DejaVuSans-Bold.ttf"
FONT_MID = "/usr/share/fonts/truetype/dejavu/DejaVuSans.ttf"

# Identificación de la prueba.
# Queda guardado en la cabecera del log de data/ y en cada registro.
TEST_ID = os.getenv("TEST_ID", "")
TEST_DISTANCIA_M = os.getenv("TEST_DISTANCIA_M", "")
TEST_NOTA = os.getenv("TEST_NOTA", "")
# Interfaz WiFi conectada al AP del nodo. Vacío = autodetectar (parece que funciona bien).
WIFI_IFACE = os.getenv("WIFI_IFACE", "")
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

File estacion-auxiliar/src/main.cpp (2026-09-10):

/**
 * @file
 * @brief Estación Agrícola - Estación auxiliar (Cheap Yellow Display)
 * @author Alejandro Provencio Sanz <aprovenci9@alumno.uned.es>
 * @date 2026-09-09
 *
 * Práctica final de Comunicaciones Inalámbricas y Protocolos para el IoT.
 *
 * Muestra las variables del nodo autónomo conectándose al broker MQTT local
 * de la estación base (sin TLS porque la librería no lo soporta).
 *
 *   WiFi -> AsyncMqttClient -> esagrau/nodos/+/telemetria -> display
 */

#include <WiFi.h>
#include <ArduinoJson.h>
#include <AsyncMqttClient.h>
#include <TFT_eSPI.h>

#include "secrets.h"

#ifndef MQTT_TOPIC_ESTADO
#define MQTT_TOPIC_ESTADO "esagrau/base/estado"
#endif

TFT_eSPI tft = TFT_eSPI();
AsyncMqttClient mqtt;

// Valores recibidos
float ta = NAN, ha = NAN, pa = NAN, lx = NAN, ts = NAN, hs = NAN,
      vb = NAN, ia = NAN, pw = NAN, rd = NAN;
int uv = -999, re = -999;
char nid[24] = "";
volatile bool hayDato = false;
byte releEstado[4] = {0, 0, 0, 0};
volatile bool hayReles = false;

// Backlight del CYD
#define TFT_BL 21

// Calibración del higrómetro como en la base
#define HUM_ADC_SECO 4095
#define HUM_ADC_SATURADO 1800

// Convierte la lectura analógica del higrómetro de suelo a porcentaje (0-100%)
int humSueloPct(int raw) {
  int rango = HUM_ADC_SECO - HUM_ADC_SATURADO;
  if (rango <= 0) return 0;
  int pct = (HUM_ADC_SECO - raw) * 100 / rango;
  if (pct < 0) pct = 0;
  if (pct > 100) pct = 100;
  return pct;
}

// Dibuja los valores en la pantalla
void dibujar() {
  tft.fillScreen(TFT_BLACK);
  tft.setTextColor(TFT_WHITE, TFT_BLACK);
  tft.setTextSize(2);

  // 28 px de alto por línea, 8 px de margen
  tft.drawString("Nodo: " + String(nid), 4, 4);
  tft.drawString("T " + String(ta, 1) + " C   H " + String(ha, 0) + "%", 4, 32);
  tft.drawString("P " + String(pa, 1) + " hPa", 4, 60);
  tft.drawString("Luz " + String(lx, 0) + " lux   UV " + String(uv), 4, 88);
  tft.drawString("Suelo " + String(ts, 1) + " C  Hum " +
                 String(isnan(hs) ? 0 : humSueloPct((int)hs)) + "%", 4, 116);
  tft.drawString("Bat " + String(vb, 2) + " V  " + String(ia, 1) + " mA", 4, 144);
  const char* rayose = (re == 3) ? "RAYO" : (re == 2) ? "DISTURBER"
                    : (re == 1) ? "RUIDO" : "OK";
  tft.drawString("Rayos " + String(rayose) +
                 (re == 3 ? "  " + String(rd, 0) + "km" : ""), 4, 172);
  if (hayReles) {
    const char* s1 = releEstado[0] ? "ON " : "OFF";
    const char* s2 = releEstado[1] ? "ON " : "OFF";
    const char* s3 = releEstado[2] ? "ON " : "OFF";
    const char* s4 = releEstado[3] ? "ON " : "OFF";
    tft.drawString(String("R ") + s1 + s2 + s3 + s4, 4, 200);
  }
}

// Función llamada cuando se recibe un mensaje MQTT
void onMessage(char* topic, char* payload, AsyncMqttClientMessageProperties properties,
               size_t len, size_t index, size_t total) {
  if (index > 0) return;  // solo primer fragmento

  // Estado de los relés (esagrau/base/estado): {"rele_1":0/1, ...}
  if (strcmp(topic, MQTT_TOPIC_ESTADO) == 0) {
    JsonDocument doc;
    if (deserializeJson(doc, payload, len)) return;
    char k[8];
    for (int i = 0; i < 4; i++) {
      snprintf(k, sizeof(k), "rele_%d", i + 1);
      releEstado[i] = doc[k] | 0;
    }
    hayReles = true;
    return;
  }

  JsonDocument doc;
  DeserializationError err = deserializeJson(doc, payload, len);
  if (err) return;
  // El broker envuelve el payload en {"enlace":{...},"dato":{...}}:
  // leer de "dato" si existe, si no del propio documento y así no hay fallos.
  JsonObject d = doc["dato"].is<JsonObject>() ? doc["dato"].as<JsonObject>() : doc.as<JsonObject>();
  ta = d["ta"] | NAN; ha = d["ha"] | NAN; pa = d["pa"] | NAN;
  lx = d["lx"] | NAN; ts = d["ts"] | NAN; hs = d["hs"] | NAN;
  vb = d["vb"] | NAN; ia = d["ia"] | NAN; pw = d["pw"] | NAN;
  rd = d["rd"] | NAN;
  uv = d["uv"] | -999; re = d["re"] | -999;
  snprintf(nid, sizeof(nid), "%s", d["nid"] | "?");
  hayDato = true;
}

// Función llamada cuando se conecta al broker MQTT
void onMqttConnect(bool sessionPresent) {
  Serial.println("MQTT conectado");
  mqtt.subscribe(MQTT_TOPIC, 1);
  mqtt.subscribe(MQTT_TOPIC_ESTADO, 1);
}

// Función llamada cuando se desconecta del broker MQTT
void onMqttDisconnect(AsyncMqttClientDisconnectReason reason) {
  Serial.printf("MQTT desconectado, motivo=%d\n", (int)reason);
}

void setup() {
  Serial.begin(115200);
  delay(200); // Nunca está de más

  pinMode(TFT_BL, OUTPUT);
  digitalWrite(TFT_BL, HIGH);

  delay(100);  // Espera a que el panel estabilice antes de inicializar
  tft.init();
  tft.setRotation(1);  // landscape 320x240 FUNCIONA
  tft.fillScreen(TFT_BLACK);
  tft.setTextColor(TFT_WHITE, TFT_BLACK);
  tft.setTextSize(2);
  
  // WiFi
  tft.drawString("WiFi...", 8, 8);
  Serial.printf("Conectando WiFi %s...\n", WIFI_SSID);
  WiFi.begin(WIFI_SSID, WIFI_PASS);
  while (WiFi.status() != WL_CONNECTED) { delay(300); }
  Serial.println("WiFi OK");
  tft.drawString("WiFi OK", 8, 8);
  
  // MQTT
  tft.drawString("Conectando...", 8, 40);
  Serial.printf("MQTT %s:%d\n", MQTT_HOST, MQTT_PORT);
  mqtt.onConnect(onMqttConnect);
  mqtt.onDisconnect(onMqttDisconnect);
  mqtt.onMessage(onMessage);
  mqtt.setServer(MQTT_HOST, MQTT_PORT);
  mqtt.setCredentials(MQTT_USER, MQTT_PASS);
  mqtt.setClientId(MQTT_CLIENT_ID);
  mqtt.setKeepAlive(60);
  mqtt.setWill("esagrau/aux/estado", 1, true, "{\"estado\":\"offline\"}");
  mqtt.connect();

  Serial.println("Estación auxiliar lista");
}

void loop() {
  if (hayDato) { dibujar(); hayDato = false; }
  delay(200);
}

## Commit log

2026-08-27 commit inicial para probar los sensores del nodo autónomo y las librerías que se usan
2026-09-02 todo funcional, pequeños problemas con activación de relés desde ubidots, falta terminar la memoria
    [nodo-autonomo.kicad_pcb, nodo-autonomo.kicad_sch]
2026-09-02 todo terminado, faltan solo las conclusiones de la memoria
2026-09-03 TERMINADA SISTEMAS DIGITALES
    [nodo-autonomo.kicad_pcb, nodo-autonomo.kicad_sch]
2026-09-04 comunicación entre nodo y estación funcionando por wifi y servidor local mqtt en la estación! comunicación con ubidots también usando mqtt, ahora la activación de relés funciona bien desde la web. Fa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
2026-09-07 aviso de nodo caído cuando se desconecta, falta probarlo bien porque el WiFi da muchos problemas y no puedo
    [entrada.py, estado.py, nodo.py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]
2026-09-08 pruebas de conexión para el USB y WiFi hechas con scripts auxiliares para sacar resultados de los logs. Cambiado método de detección de nodo desconectado que era muy sensible. Configurado INA226 en e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
2026-09-08 Funcionando enlace con ESP-NOW. Refactorizado el programa de la estación base para que pueda funcionar por USB, WiFi o ESP-NOW según una variable de ejecución. Creado firmware simple para el ESP32-C3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
2026-09-09 base para la estación auxiliar, falta probarlo
2026-09-09 preparado para usar meshtastic a través de 2 placas faketec, no funciona...
2026-09-09 Funcionando por Meshtastic! era problema de los nombres de los puertos del Faketec. Reducido tamaño del payload también porque daba problemas.
    [gateway_serial.py, main.cpp]
2026-09-09 reducido más el tamaño del payload que manda el nodo a la base para entrar bien dentro de los límites de meshtastic y variables aplanadas al estilo de las que mandábamos a ubidots. usando TLS para co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
    [config.py, main.cpp, mqtt_local.py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]
2026-09-10 la batería necesita 2 decimales sí o sí
2026-09-10 memoria hecha a falta de revisarla
